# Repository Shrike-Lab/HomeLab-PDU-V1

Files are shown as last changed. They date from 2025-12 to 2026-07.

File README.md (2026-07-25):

<div align="center">
  Shrike Lab logo
  
  [Website](https://www.shrikelab.co) | [YouTube](https://www.youtube.com/@ShrikeLab)
  
</div>
<p align="center">
  <a href="https://patreon.com/shrikelab">
    
  </a>
  <a href="https://ko-fi.com/shrikelab">
    
  </a>
</p>

# **ShrikeLab PDU V1** - 5 & 10 port USB-C PDUs for 10" and 19" racks
These PSUs are power delivery solutions for micro PC clusters and homelabs that suits either 10" and 19" racks. All variants are built around a Meanwell HRP-300-24 featuring either 5 or 10 USB-C power delivery ports enclosed in sheet metal or 3D printed ABS/ASA housings. 

<div align="center">
  <a
    href="https://www.Shrikelab.co" title="Kits and PCBs available now!">Kits and PCBs available now!
  </a>  
</div>

---

<p float="center">
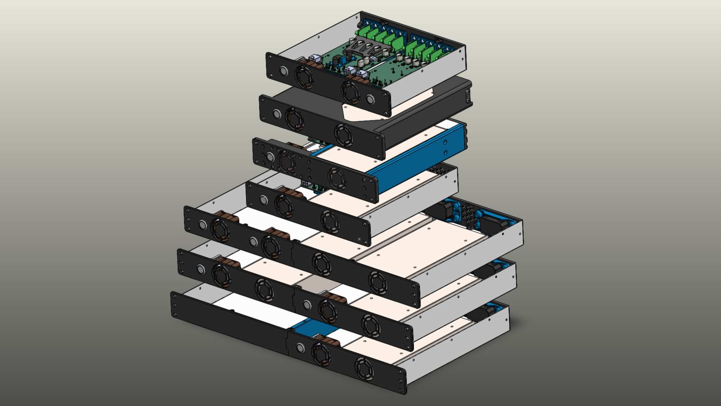
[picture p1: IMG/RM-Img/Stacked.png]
   
</p>

Mini and micro labs are a great solution for homelabbing, but the power delivery options are often bulky and hard to manage due to the need for an individual power brick per computer.
This project helps fix this by consolidating power delivery for up to 10 65W micro PCs into a single unit that fits in either a 10" or 19" 1U rack. This differs from a conventional multi-port USB PD hub by not needing to re-negotiate any power delivery voltages when a unit is turned off or unplugged, or when the power load across ports changes drastically. Also the packaging is designed specifially for rack mounting, with active cooling and simple power switching.

[**Design and build video here**](https://www.youtube.com/watch?v=8tTG0TBM7ts)

[**Follow-up and testing video here**](https://www.youtube.com/watch?v=Ig7oZpujHtc&t)

<br>

### Features:
- Both 19" and 10" variants
- Up to 10 x 65W USB-C outputs
- 1U Height
- Active cooling
- Sheet metal housing or fully 3D printable
- All variants built around a Meanwell HRP-300-24
- All 3D printed parts fit on a 220x220mm print bed

<br>

### Repo Content:
- **Assembly** - Renders and references for main and sub-assemblies, plus bill of material for each variant
  - **CAD** - CAD files for all varients, universal files and drawings of components
    - **Universal** - Files thats are used for multiple variants
    - 10in_Single
    - 10in_Dual
    - 10in_3D_Modular
    - 10in_3D_Unibody
    - 19in_Single
    - 19in_Dual
    - 19in_Dual_SBS
    - **Blanks** - STP files for customisation
    - **Universal** - STL and STP files that are used for multiple variants
  - **Drawings** - Drawings of components and wiring
    - **Electrical** - Harness pinouts and drawings of electronic components
    -  **Hardware** - Drawings of hardware along with sheet metal engineering drawings
- **IMG** - Images
- **PCB** - PCB gerber manufacturing files

<br>

### Issues:
There's a lot of ground to cover with this repo, so if you find an issue, please raise it with the GitHub issue system and it will get fixed. If you have questions about assembly or any of the variants, please make sure you have read through all the readme content before reaching out to save on time.

### ToDo:
- Export all sheet metal STEP files in 1.2mm thickness for imperial

# Variants:
All variants are built around a Meanwell HRP-300-24 and the same PCB. The housings are designed to fit in 1U of space in either a 10in and 19in server rack. 

## 10 Inch - Single:
The original 10" enclosure, a sheet metal body + lid make up the housing, with a 3D printed front and rear. 5 outputs.
<p float="center">
   
</p>
<p float="center">
   
   
</p>

[Bill of materials](https://github.com/Shrike-Lab/MiniLab-PSU/blob/main/ASSEMBLY/README.md#10-inch---single)

<br>

## 10 Inch - 3D Printed - Unibody:
10" printed unibody enclosure, made to be as easy as possible with minimal additional hardware, with the trade-off of being a little harder to print. No inserts required, all bolts thread directly into the print material. Small hatch for attaching button + fan and connecting wiring to PCB.
<p float="center">
   
</p>
<p float="center">
   
   
</p>

[Bill of materials](https://github.com/Shrike-Lab/MiniLab-PSU/blob/main/ASSEMBLY/README.md#10-inch---3d-printed---unibody)

<br>

## 10 Inch - 3D Printed - Modular:
10" printed enclosure, made to be more modular and mod-friendly but requires more M3 inserts and bolts to assebmle. The CAD folder for this variant also includes 'flipped' front and rear STLs that have the mounting tabs swapped, so that the USB-C ports and power intput will face the front of the rack instead of the rear.
<p float="center">
   
</p>
<p float="center">
   
   
</p>

[Bill of materials](https://github.com/Shrike-Lab/MiniLab-PSU/blob/main/ASSEMBLY/README.md#10-inch---3d-printed---modular)

<br>

## 10 Inch - Dual:
10" enclosure for external PSU's. 10 outputs, intended for use with alternative power sources like battery or solar, or for up-cycling external 300W PSUs.
<p float="center">
   
</p>
<p float="center">
   
   
</p>

[Bill of materials](https://github.com/Shrike-Lab/MiniLab-PSU/blob/main/ASSEMBLY/README.md#10-inch---dual)

<br>

## 19 Inch - Single:
19" inch version of 5 output variant. Additional space could be used for cable / tiny-mini-micro storage.
<p float="center">
   
</p>
<p float="center">
   
   
</p>

[Bill of materials](https://github.com/Shrike-Lab/MiniLab-PSU/blob/main/ASSEMBLY/README.md#19-inch---single)

<br>

## 19 Inch - Dual:
19" with 10 outputs from 2 x internal assemblies.
<p float="center">
   
</p>
<p float="center">
   
   
</p>

[Bill of materials](https://github.com/Shrike-Lab/MiniLab-PSU/blob/main/ASSEMBLY/README.md#19-inch---dual)

<br>

## 19 Inch - SBS:
For people that couldn't possibly deal with a power input in the middle of the housing, this version has matching components side-by-side so inputs and outputs can be coordinated easier. One harness will require extending due to the layout.
<p float="center">
   
</p>
<p float="center">
   
   
</p>

[Bill of materials](https://github.com/Shrike-Lab/MiniLab-PSU/blob/main/ASSEMBLY/README.md#19-inch---dual---sbs)

<br>

# Disclaimer:

If you build, modify, or use this project, you do so entirely at your own risk. The author provides these files without any warranty or guarantee of safety, reliability, or fitness for any particular purpose, and accepts no liability for any damage, injury, loss, or other consequences resulting from their use.

# License:
This project is licensed under the CERN Open Hardware Licence Version 2 - Strongly Reciprocal (CERN-OHL-S v2).
You may use, study, modify, and distribute this design and its documentation, provided that any derivatives are licensed under the same terms. Source design files must be made available to anyone who receives the hardware or design files.

Learn more about the license at [ohwr.org](https://ohwr.org).

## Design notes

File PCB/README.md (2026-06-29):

# PCB:
All variants use the same 2 layer 1.6mm thick PCB. This folder contains production files that can be uploaded to a PCB service for manufacturing, JLCPCB is my go-to. PCB assembly is recommended unless you have capability to do SMD soldering with either a hot air station or reflow oven.
There is currently no option for a through-hole variant because the tranistor does not come in a TH package.

**Parameters for PCB manufacturing:**
- 2 Oz copper trace weight - This is a must for current rating
- 1.6mm PCB thickness

<br>

### PCB Notes:
- You can use either an LM2596S or and MP1584EN. Just move the mounting headers to the corresponding holes.
- Connectors J19, J20, J21, J22 are optional. Either used for additional power output, or testing.
- After assembly, set fan header output voltage **before** plugging any fans in.

<br>

### Power Delivery Modules:
THe board assembly contains 5 USB-C power delivery modules that are based on an XPM52C with the following power profiles.

12V/3A, 15V/3A, 20V/3.25A

**Low Power PDO:** 5V/3A, 9V/3A, 12V/2.5A, 20V/1.5A

**High Power PDO:** 5V/3A, 9V/3A, 12V/3A

There's an interesting article [here](https://mysku.club/blog/aliexpress/101076.html) (is in Russian so will need translating) that goes over the thermal performance of the power delivery chips at 65W.

<p float="center">
   
</p>

### Buck Converter:
To power the 40mm chassis fans the main 24V rail needs to be stepped down to 12V. This can be done with either an LM2596S or MP1584EN, on the PCB there's header holes and labels for both. The LM2596S is much more popular, but the MP1584EN is newer and has less EMC. MP1584EN comes in multiple variants, **make sure to get the variable one so you're able to tune the fan voltage**.

<p float="center">
   
   
</p>

### Cooling Fan:
The cooling fan used for the PCB is a Noctua NF-A4x20 powered via 12V stepped down from the switched 24V output. This fan is 40mmx40mm and 20mm thick. The fan output on the main PCB is DC only, so the 3-Pin FLX variant are recommended, however the 4-pin PWM version will also work. When assembling the main PCB, make sure to adjust the buck converter output voltage down below 12V before plugging in any fans. The RPM of the fans is adjusted by tuning the voltage output of the buck converter.

Replacing the internal fan of the Meanwell PSU requires opening the power supply unit. This should only be attempted by qualified personnel.
Mains voltage is present inside the PSU enclosure and can cause serious injury or death. Even with the unit powered off and unplugged, capacitors inside the PSU may retain a lethal charge for an extended period. Do not touch any internal components unless you are certain the unit has been fully discharged.

If you chose to replace the PSU fan, it can be plugged into the second header on the main PCB.

The fan headers on the PCB are 3 pin 2.54mm, standard DC fan headers.

### Wiring:
There are two harnesses per set of internal electronics, one for main power and one for the button. The drawings can be found [here](https://github.com/Shrike-Lab/MiniLab-PSU/tree/main/ASSEMBLY/DRAWINGS/Electrial).

- **I would highly recommend you double check the pinout of your latching button before wiring it up, as they can differ from brand to brand.**

| Part | Harness | Quantity Per Assembly | Link |
| --- | --- | --- | --- |
| Ring spade | 24V Power | 9 | https://www.digikey.com/en/products/detail/molex/0193240008/3884473 |
| PCB Connector | 24V Power & Button | 2 | https://www.digikey.com/en/products/detail/molex/0039012060/61379?s=N4IgTCBcDaIOoFkDMB2ADGAtAOQCIgF0BfIA |
| Crimp | 24V Power & Button | 12 | https://www.digikey.com/en/products/detail/molex/0039000039/61448?s=N4IgTCBcDaIOoFkwFYAMBGAtAOQCIgF0BfIA |
| IEC Terminals | Mains Power | 7 | https://www.digikey.com/en/products/detail/molex/0190030011/279039 |

<br>

## PCB Component BOM:

| Type | Key | Value | Footprint | Quantity | Component | Commment |
| --- | --- | --- | --- | --- | --- | --- |
| Capacitor | C1,C2,C5,C6,C7,C8,C9 | 470uF | THT-CP_Radial_D10 | 6 | - | - |
| Capacitor | C3 | 1uF | 1206 | 1 | - | - |
| Capacitor | C4 | 220nF | 0603 | 1 | - | - |
| Capacitor | C10,C11,C12,C13,C14  | 1uF | 1206 | 5 | - | - |
| Capacitor | C15,C16,C17,C18,C19  | .1uF | 0603 | 5 | - | - |
| Resistor  | R1 | 4.7k | 1206 | 1 | - | - |
| Resistor  | R2 | 47k | 0603 | 1 | - | - |
| Resistor  | R3 | 100 | 0603 | 1 | - | - |
| Resistor  | R4 | 100k | 0603 | 1 | - | - |
| Diode | D1,D2,D3,D4,D5 | SMBJ26A | D_SMB | 5 | - | - |
| Diode | D6 | SMCJ26A | D_SMC | 1 | - | - |
| Diode | D7 | Zener | SOD-123 | 1 | BZT52C12 | - |
| Fuse | F1 | 15A | 2410 | 1 | 0451020.MRL | - |
| Fuse | F2,F3,F4F5,F6 | 3A | 1206 | 5 | 1206FA-4A | - |
| Connector | J1,J2 | - | Molex_5569-06A2 | 2 | Molex_5569-06A2 | Power and button |
| Connector | J13,J14,J15,J16 | - | 1x01_2.54mm | 4 | 1x01_2.54mm | Buck converter |
| Connector | J17,J18 | - | Molex_2272031 | 2 | Molex_2272031 | Fans |
| Connector | J19,J21,J22 | - | 1x02_2.54mm | 3 | 1x02_2.54mm | Debug |
| Connector | J20 | - | JST_PH-K_1x02 | 1 | JST_PH-K_1x02 | PSU sense |
| Mosfet | Q1 | - | TO-263-2L | 1 | NCEP40PT15D | - |

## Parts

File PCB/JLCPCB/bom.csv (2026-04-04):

Designator | Footprint | Quantity | Value | LCSC Part #
C1, C2, C5, C6, C7, C8, C9 | CP_Elec_10x10 | 7 | 470uF
C10, C11, C12, C13, C14, C3 | 1206 | 6 | 1uF
C15, C16, C17, C18, C19 | 0603 | 5 | .1uF
C4 | 0603 | 1 | 220nF
D1, D2, D3, D4, D5 | D_SMB | 5 | SMBJ26A
D6 | D_SMB-SMC_Universal_Handsoldering | 1 | SMCJ26A
D7 | D_SOD-123 | 1 | 12V Zener
F1 | 2410 Fuse | 1 | Fuse_0
F2 | 1206 | 1 | Fuse_1
F3 | 1206 | 1 | Fuse_2
F4 | 1206 | 1 | Fuse_3
F5 | 1206 | 1 | Fuse_4
F6 | 1206 | 1 | Fuse_5
J1 | Molex_Mini-Fit_Jr_5569-06A2_2x03_P4.20mm_Horizontal | 1 | Power_Input
J10 | PinHeader_1x01_P2.54mm_Vertical | 1 | 3_Neg
J11 | PinHeader_1x01_P2.54mm_Vertical | 1 | 4_Neg
J12 | PinHeader_1x01_P2.54mm_Vertical | 1 | 5_Neg
J17 | PinHeader_1x03_P2.54mm_Vertical | 1 | Fan_1
J18 | PinHeader_1x03_P2.54mm_Vertical | 1 | Fan_2
J2 | Molex_Mini-Fit_Jr_5569-06A2_2x03_P4.20mm_Horizontal | 1 | Button_Input
J20 | JST_PH_B2B-PH-K_1x02_P2.00mm_Vertical | 1 | Sens
J3 | PinHeader_1x01_P2.54mm_Vertical | 1 | 1_Pos
J4 | PinHeader_1x01_P2.54mm_Vertical | 1 | 2_Pos
J5 | PinHeader_1x01_P2.54mm_Vertical | 1 | 3_Pos
J6 | PinHeader_1x01_P2.54mm_Vertical | 1 | 4_Pos
J7 | PinHeader_1x01_P2.54mm_Vertical | 1 | 5_Pos
J8 | PinHeader_1x01_P2.54mm_Vertical | 1 | 1_Neg
J9 | PinHeader_1x01_P2.54mm_Vertical | 1 | 2_Neg
Q1 | TO-263-3_TabPin2 | 1 | NCEP40PT15D | IRF9540NPBF
R1 | 1206 | 1 | 4.7k
R2 | 0603 | 1 | 47k
R3 | 0603 | 1 | 100
R4 | 0603 | 1 | 100k

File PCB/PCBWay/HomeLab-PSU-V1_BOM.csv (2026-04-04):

Designator | Quantity | Value | Footprint | Package | MPN | DNP | Mount_Type | Description | Digi-Key_PN | Category | Family | DK_Datasheet_Link | DK_Detail_Page | Description_1 | Manufacturer | Status
C1, C2, C5, C6, C7, C8, C9 | 7 | 470uF | CP_Elec_10x10 |  |  |  | smt | Unpolarized capacitor
C10, C11, C12, C13, C14, C3 | 6 | 1uF | C_1206_3216Metric_Pad1.33x1.80mm_HandSolder |  |  |  | smt | Unpolarized capacitor
C15, C16, C17, C18, C19 | 5 | .1uF | C_0603_1608Metric_Pad1.08x0.95mm_HandSolder |  |  |  | smt | Unpolarized capacitor
C4 | 1 | 220nF | C_0603_1608Metric_Pad1.08x0.95mm_HandSolder |  |  |  | smt | Unpolarized capacitor
D1, D2, D3, D4, D5 | 5 | SMBJ26A | D_SMB |  |  |  | smt | 20V 2A Schottky Barrier Rectifier Diode, SMB
D6 | 1 | SMCJ26A | D_SMB-SMC_Universal_Handsoldering |  |  |  | smt | 20V 2A Schottky Barrier Rectifier Diode, SMB
D7 | 1 | 12V Zener | D_SOD-123 |  |  |  | smt | Zener diode
F1 | 1 | Fuse_0 | 2410 Fuse |  |  |  | tht | Fuse
F2 | 1 | Fuse_1 | Fuse_1206_3216Metric_Pad1.42x1.75mm_HandSolder |  |  |  | smt | Fuse
F3 | 1 | Fuse_2 | Fuse_1206_3216Metric_Pad1.42x1.75mm_HandSolder |  |  |  | smt | Fuse
F4 | 1 | Fuse_3 | Fuse_1206_3216Metric_Pad1.42x1.75mm_HandSolder |  |  |  | smt | Fuse
F5 | 1 | Fuse_4 | Fuse_1206_3216Metric_Pad1.42x1.75mm_HandSolder |  |  |  | smt | Fuse
F6 | 1 | Fuse_5 | Fuse_1206_3216Metric_Pad1.42x1.75mm_HandSolder |  |  |  | smt | Fuse
J1 | 1 | Power_Input | Molex_Mini-Fit_Jr_5569-06A2_2x03_P4.20mm_Horizontal |  |  |  | tht | Generic connector, double row, 02x03, counter clockwise pin numbering scheme (similar to DIP package numbering), script generated (kicad-library-utils/schlib/autogen/connector/)
J10 | 1 | 3_Neg | PinHeader_1x01_P2.54mm_Vertical |  |  |  | tht | Generic connector, single row, 01x01, script generated
J11 | 1 | 4_Neg | PinHeader_1x01_P2.54mm_Vertical |  |  |  | tht | Generic connector, single row, 01x01, script generated
J12 | 1 | 5_Neg | PinHeader_1x01_P2.54mm_Vertical |  |  |  | tht | Generic connector, single row, 01x01, script generated
J17 | 1 | Fan_1 | PinHeader_1x03_P2.54mm_Vertical |  |  |  | tht | Generic connector, single row, 01x03, script generated
J18 | 1 | Fan_2 | PinHeader_1x03_P2.54mm_Vertical |  |  |  | tht | Generic connector, single row, 01x03, script generated
J2 | 1 | Button_Input | Molex_Mini-Fit_Jr_5569-06A2_2x03_P4.20mm_Horizontal |  |  |  | tht | Generic connector, double row, 02x03, counter clockwise pin numbering scheme (similar to DIP package numbering), script generated (kicad-library-utils/schlib/autogen/connector/)
J20 | 1 | Sens | JST_PH_B2B-PH-K_1x02_P2.00mm_Vertical |  |  |  | tht | Generic connector, single row, 01x02, script generated
J3 | 1 | 1_Pos | PinHeader_1x01_P2.54mm_Vertical |  |  |  | tht | Generic connector, single row, 01x01, script generated
J4 | 1 | 2_Pos | PinHeader_1x01_P2.54mm_Vertical |  |  |  | tht | Generic connector, single row, 01x01, script generated
J5 | 1 | 3_Pos | PinHeader_1x01_P2.54mm_Vertical |  |  |  | tht | Generic connector, single row, 01x01, script generated
J6 | 1 | 4_Pos | PinHeader_1x01_P2.54mm_Vertical |  |  |  | tht | Generic connector, single row, 01x01, script generated
J7 | 1 | 5_Pos | PinHeader_1x01_P2.54mm_Vertical |  |  |  | tht | Generic connector, single row, 01x01, script generated
J8 | 1 | 1_Neg | PinHeader_1x01_P2.54mm_Vertical |  |  |  | tht | Generic connector, single row, 01x01, script generated
J9 | 1 | 2_Neg | PinHeader_1x01_P2.54mm_Vertical |  |  |  | tht | Generic connector, single row, 01x01, script generated
Q1 | 1 | NCEP40PT15D | TO-263-3_TabPin2 |  | IRF9540NPBF |  | smt | MOSFET P-CH 100V 23A TO-220AB | IRF9540NPBF-ND | Discrete Semiconductor Products | Transistors - FETs, MOSFETs - Single | https://www.infineon.com/dgdl/irf9540npbf.pdf?fileId=5546d462533600a401535611cfa21dc8 | /product-detail/en/infineon-technologies/IRF9540NPBF/IRF9540NPBF-ND/812088 | MOSFET P-CH 100V 23A TO-220AB | Infineon Technologies | Active
R1 | 1 | 4.7k | R_1206_3216Metric |  |  |  | smt | Resistor
R2 | 1 | 47k | R_0603_1608Metric |  |  |  | smt | Resistor
R3 | 1 | 100 | R_0603_1608Metric |  |  |  | smt | Resistor
R4 | 1 | 100k | R_0603_1608Metric |  |  |  | smt | Resistor

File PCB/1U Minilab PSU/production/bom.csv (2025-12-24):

Designator | Footprint | Quantity | Value | LCSC Part #
C1 | 0603 | 1 | 220nF
C10, C13, C19, C2, C7 | 0603 | 5 | .1uF
C11, C14, C17, C3, C4, C8 | CP_Radial_D10.0mm_P5.00mm | 6 | 470uF
C12, C15, C18, C5, C6, C9 | 1206 | 6 | 1uF
C16 | CP_Radial_D10.0mm_P5.00mm | 1 | 1000uF
D1, D2, D3, D4, D7 | D_SMB | 5 | SMBJ24A
D5 | D_SOD-123 | 1 | D_Zener
D6 | D_SMB-SMC_Universal_Handsoldering | 1 | SMCJ24A
F1 | 1206 | 1 | Fuse_1
F2 | 1206 | 1 | Fuse_2
F3 | 1206 | 1 | Fuse_3
F4 | 1206 | 1 | Fuse_4
F5 | 1206 | 1 | Fuse_0
F6 | 1206 | 1 | Fuse_5
J1 | Molex_Micro-Fit_3.0_43045-0600_2x03_P3.00mm_Horizontal | 1 | Power_Input
J10 | PinHeader_1x01_P2.54mm_Vertical | 1 | 4_Neg
J11, J12 | PinHeader_1x03_P2.54mm_Vertical | 2 | Conn_01x03_Pin
J13 | PinHeader_1x02_P2.54mm_Vertical | 1 | Conn_01x02_Pin
J14 | PinHeader_1x01_P2.54mm_Vertical | 1 | Fan-IN
J15 | PinHeader_1x01_P2.54mm_Vertical | 1 | Fan+IN
J16 | PinHeader_1x01_P2.54mm_Vertical | 1 | Fan+Out
J17 | PinHeader_1x01_P2.54mm_Vertical | 1 | Fan-Out
J18 | PinHeader_1x01_P2.54mm_Vertical | 1 | 5_Pos
J19 | PinHeader_1x01_P2.54mm_Vertical | 1 | 5_Neg
J2 | Molex_Micro-Fit_3.0_43045-0600_2x03_P3.00mm_Horizontal | 1 | Button_Input
J20 | PinHeader_1x02_P2.54mm_Vertical | 1 | Sens
J21, J22 | PinHeader_1x02_P2.54mm_Vertical | 2 | 24V
J3 | PinHeader_1x01_P2.54mm_Vertical | 1 | 1_Pos
J4 | PinHeader_1x01_P2.54mm_Vertical | 1 | 1_Neg
J5 | PinHeader_1x01_P2.54mm_Vertical | 1 | 2_Pos
J6 | PinHeader_1x01_P2.54mm_Vertical | 1 | 2_Neg
J7 | PinHeader_1x01_P2.54mm_Vertical | 1 | 3_Pos
J8 | PinHeader_1x01_P2.54mm_Vertical | 1 | 3_Neg
J9 | PinHeader_1x01_P2.54mm_Vertical | 1 | 4_Pos
Q4 | TO-252-3_TabPin2 | 1 | DMP4010SK3-13 | IRF9540NPBF
R3 | 0603 | 1 | 100
R4 | 0603 | 1 | 47k
R5 | 1206 | 1 | 4.7k
R6 | 0603 | 1 | 100k

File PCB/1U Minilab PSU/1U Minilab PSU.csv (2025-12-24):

Reference | Qty | Value | DNP | Exclude from BOM | Exclude from Board | Footprint | Datasheet | Part
C1 | 1 | 220nF |  |  |  | Capacitor_SMD:C_0603_1608Metric_Pad1.08x0.95mm_HandSolder | ~
C2,C7,C10,C13 | 4 | .1uF |  |  |  | Capacitor_SMD:C_0603_1608Metric_Pad1.08x0.95mm_HandSolder | ~
C3,C4,C8,C11,C14 | 5 | 470uF |  |  |  | Capacitor_THT:CP_Radial_D10.0mm_P5.00mm | ~ | https://www.digikey.co.nz/en/products/detail/kemet/A759MS477M1EAAE020/13676499
C5,C6,C9,C12,C15 | 5 | 1uF |  |  |  | Capacitor_SMD:C_1206_3216Metric_Pad1.33x1.80mm_HandSolder | ~
C16 | 1 | 1000uF |  |  |  | Capacitor_THT:CP_Radial_D10.0mm_P5.00mm | ~
D1,D2,D3,D4 | 4 | SMBJ24A |  |  |  | Diode_SMD:D_SMA-SMB_Universal_Handsoldering
D5 | 1 | D_Zener |  |  |  | Diode_SMD:D_SOD-123 | ~
D6 | 1 | SMCJ24A |  |  |  | Diode_SMD:D_SMB-SMC_Universal_Handsoldering
F1 | 1 | Fuse_1 |  |  |  | Fuse:Fuse_1206_3216Metric_Pad1.42x1.75mm_HandSolder | ~ | https://www.digikey.co.nz/en/products/detail/bourns-inc/SF-1206F350M-2/14320025
F2 | 1 | Fuse_2 |  |  |  | Fuse:Fuse_1206_3216Metric_Pad1.42x1.75mm_HandSolder | ~ | https://www.digikey.co.nz/en/products/detail/bourns-inc/SF-1206F350M-2/14320025
F3 | 1 | Fuse_3 |  |  |  | Fuse:Fuse_1206_3216Metric_Pad1.42x1.75mm_HandSolder | ~ | https://www.digikey.co.nz/en/products/detail/bourns-inc/SF-1206F350M-2/14320025
F4 | 1 | Fuse_4 |  |  |  | Fuse:Fuse_1206_3216Metric_Pad1.42x1.75mm_HandSolder | ~ | https://www.digikey.co.nz/en/products/detail/bourns-inc/SF-1206F350M-2/14320025
F5 | 1 | Fuse_0 |  |  |  | Fuse:Fuse_1206_3216Metric_Pad1.42x1.75mm_HandSolder | ~ | https://www.digikey.co.nz/en/products/detail/schurter-inc/3413-0329-22/2644176
Q4 | 1 | DMP4010SK3-13 |  |  |  | Package_TO_SOT_SMD:TO-252-3_TabPin2
R2 | 1 | 0 | DNP |  |  | Resistor_SMD:R_1206_3216Metric | ~
R3 | 1 | 100 |  |  |  | Resistor_SMD:R_0603_1608Metric | ~
R4 | 1 | 47k |  |  |  | Resistor_SMD:R_0603_1608Metric | ~
R5 | 1 | 4.7k |  |  |  | Resistor_SMD:R_1206_3216Metric | ~
R6 | 1 | 100k |  |  |  | Resistor_SMD:R_0603_1608Metric | ~

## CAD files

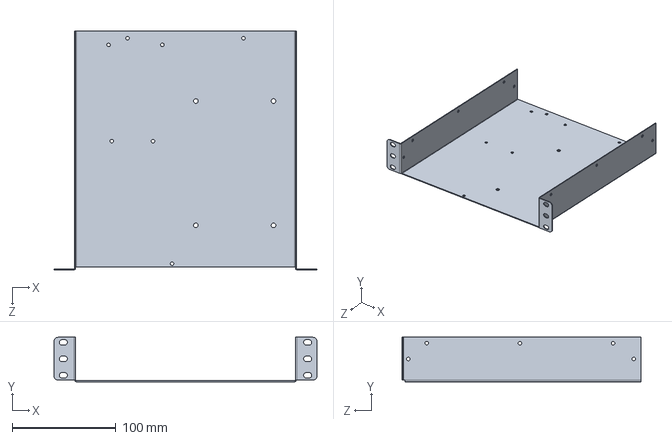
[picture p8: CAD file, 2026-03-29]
ASSEMBLY/CAD/10in_Single/Metal_Tray.STEP
254.0 x 43.0 x 230.5 mm

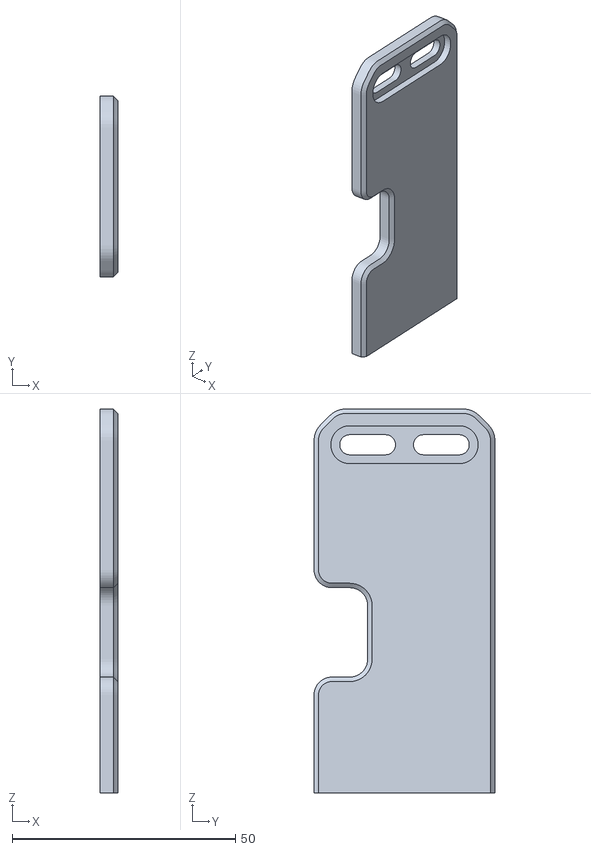
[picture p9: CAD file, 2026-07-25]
ASSEMBLY/CAD/19in_Dual_SBS/19in_Dual_SBS-Divider.STL
4.00 x 40.5 x 86.0

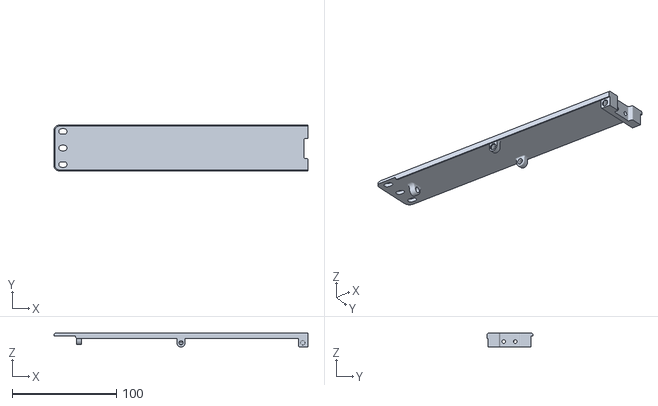
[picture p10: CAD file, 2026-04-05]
ASSEMBLY/CAD/19in_Single/19in_Single-Rear_2.stl
244.1 x 44.0 x 13.4

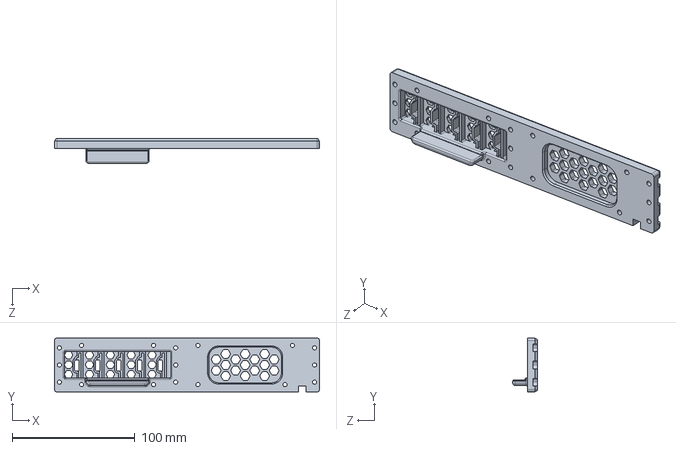
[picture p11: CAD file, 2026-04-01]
ASSEMBLY/CAD/Blanks/10in_Mod-Back-BLANK.STEP
216.0 x 44.0 x 20.0 mm

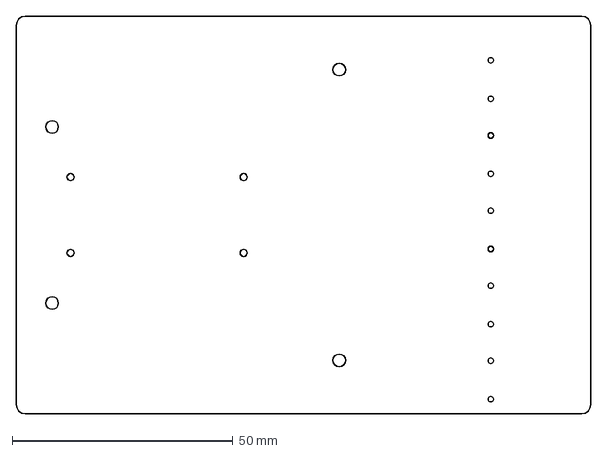
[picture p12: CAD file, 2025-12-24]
PCB/1U Minilab PSU/Breakout PCB Outline.DXF
130.0 x 90.0 mm

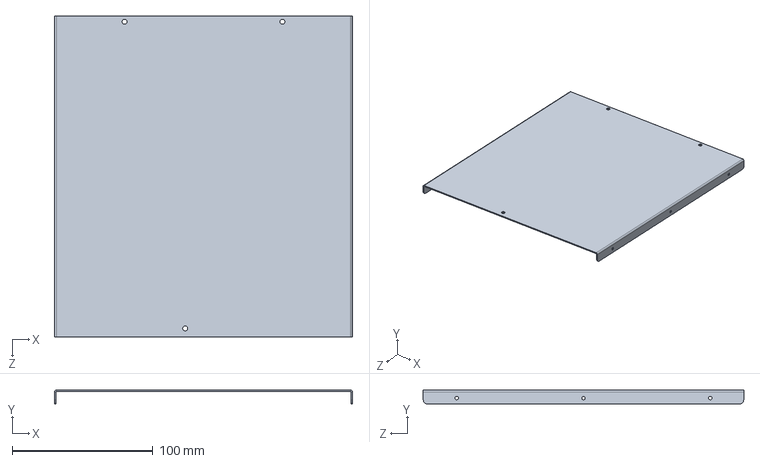
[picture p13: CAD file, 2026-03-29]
ASSEMBLY/CAD/10in_Single/Metal_Lid.STEP
211.5 x 10.0 x 227.5 mm

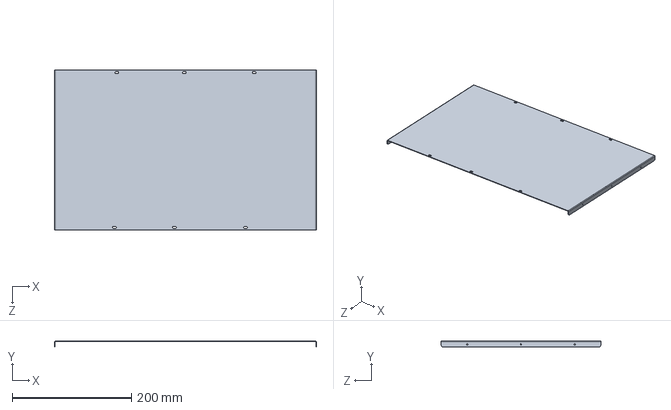
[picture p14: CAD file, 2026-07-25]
ASSEMBLY/CAD/19in_Dual_SBS/19in_Dual_SBS-Lid.stp
438.7 x 10.0 x 267.1 mm

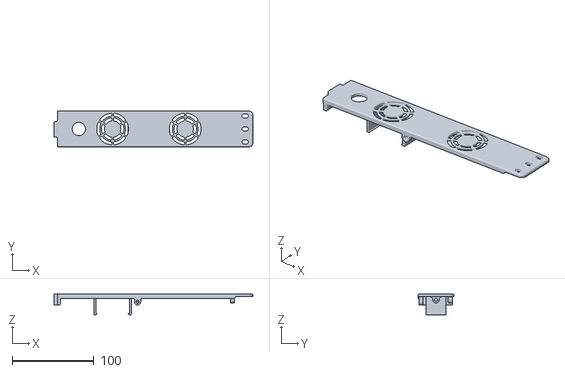
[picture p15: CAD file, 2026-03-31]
ASSEMBLY/CAD/19in_Single/19in_Single-Front_1.stl
244.0 x 44.0 x 25.5

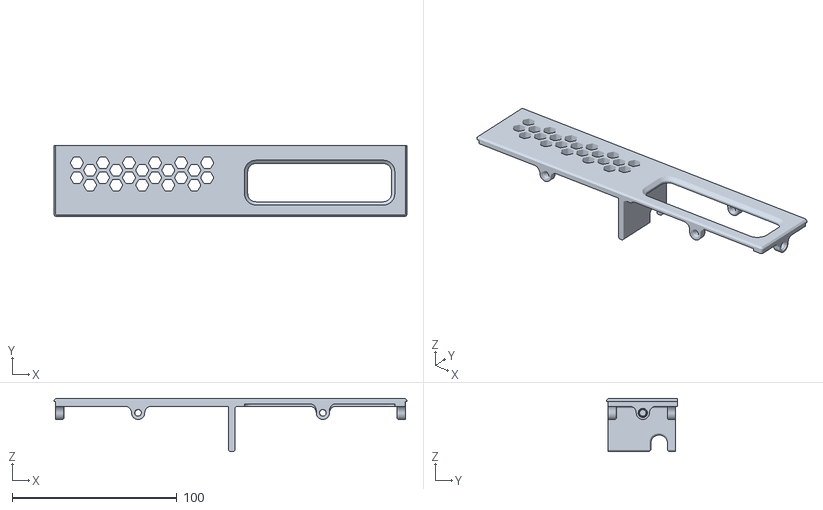
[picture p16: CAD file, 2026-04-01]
ASSEMBLY/CAD/Blanks/10in_Single-Back-BLANK.STL
214.0 x 43.0 x 32.3

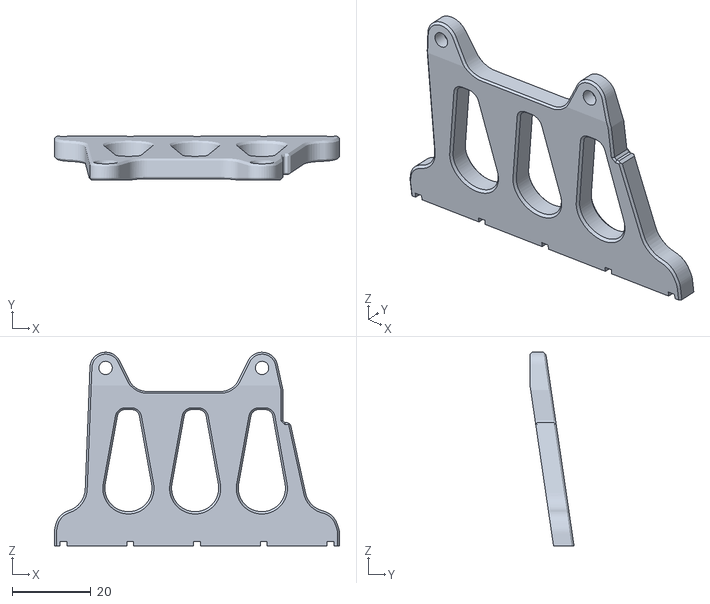
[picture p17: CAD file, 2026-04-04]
ASSEMBLY/CAD/Universal/Reinforcement_Bracket.stl
72.6 x 11.2 x 49.3

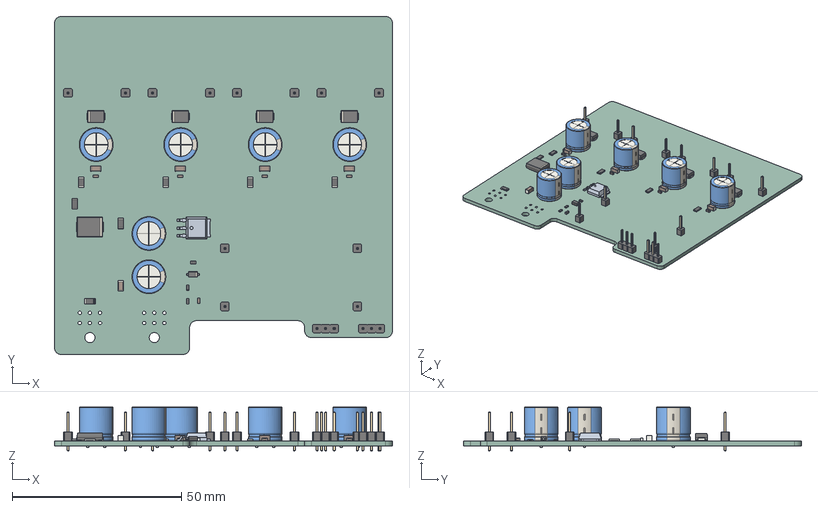
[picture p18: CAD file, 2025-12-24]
PCB/1U Minilab PSU/1U Minilab PSU.step
100.0 x 100.0 x 13.0 mm
C_1206_3216Metric x 5
PinHeader_1x01_P2.54mm_Vertical x 12
CP_Radial_D10.0mm_P5.00mm x 6
D_SMB x 4
D_SMC
1U Minilab PSU 1.11.1
PinHeader_1x03_P2.54mm_Vertical x 2
Fuse_1206_3216Metric x 5
C_0603_1608Metric x 5
R_0603_1608Metric x 3
R_1206_3216Metric x 2
D_SOD-123
1U Minilab PSU_PCB

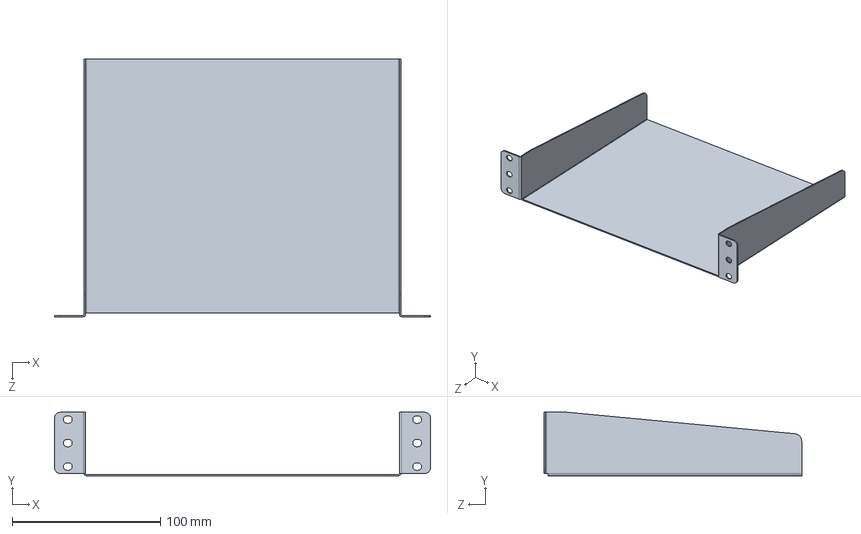
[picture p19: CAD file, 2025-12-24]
PCB/1U Minilab PSU/CAD/Optiplex_Tray.SLDPRT
254.0 x 43.0 x 174.0 mm

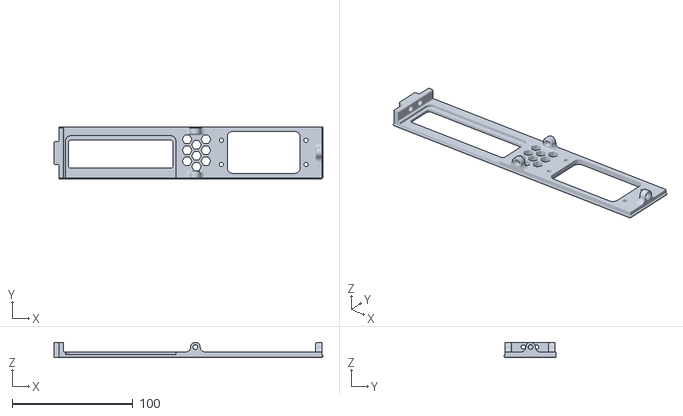
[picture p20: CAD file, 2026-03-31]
ASSEMBLY/CAD/19in_Single/19in_Single-Rear_1.stl
222.4 x 43.0 x 12.8

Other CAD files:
ASSEMBLY/CAD/19in_Dual/19in_Dual-Front_2.stl
ASSEMBLY/CAD/Universal/19in_Single-Rear_2-BLANK.STEP
PCB/1U Minilab PSU/CAD/Metal_Tray.SLDPRT
ASSEMBLY/CAD/19in_Dual/19in_Dual-Rear_2.stl
ASSEMBLY/CAD/19in_Dual/19in_Dual-Rear_1.stl
ASSEMBLY/CAD/19in_Dual/19in_Dual-Front_1.stl
ASSEMBLY/CAD/19in_Single/19in_Single-Front_2.3mf
ASSEMBLY/CAD/19in_Single/19in_Single-Front_2.stl
ASSEMBLY/CAD/Blanks/10in_Uni-Tray-BLANK.stl.STEP
ASSEMBLY/CAD/Universal/IEC_Bracket.stl
ASSEMBLY/CAD/Universal/PCB_Tray.stl
PCB/1U Minilab PSU/CAD/Metal_Lid.DXF
PCB/1U Minilab PSU/CAD/Metal_Lid.SLDPRT
PCB/1U Minilab PSU/CAD/Metal_Tray.DXF
PCB/1U Minilab PSU/CAD/Optiplex_Tray.DXF

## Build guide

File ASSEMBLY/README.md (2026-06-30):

# Assembly:
This section contains the bill of materials for each variant, as well as renders and exploded views of the sub-assemblies.

- All trays mount to the racks with M5 hardware
- For 3D printing all files have been exported as an STL
- Blank parts have been exported as an STP to help editing
- Metal parts are exported as an STP
- As the metal housing lids require tapping, there is an engineering drawing in the [drawings folder](https://github.com/Shrike-Lab/MiniLab-PSU/tree/main/ASSEMBLY/DRAWINGS/Hardware)
- Highly recommended to order extra insert and bolt hardware

**All variants contain the following components:**
| Component |Link/Location | Source |
| --- |--- | --- |
| PDU PCB Ver 1.0 | [Drawing](https://github.com/Shrike-Lab/HomeLab-PDU-V1/blob/main/PCB/Minilab_PDU_V1.zip) | Shrikelab kit or buy PCB manufacturing service|
| 16mm Button | [Drawing](https://github.com/Shrike-Lab/HomeLab-PDU-V1/blob/main/ASSEMBLY/DRAWINGS/Electrial/Harness-Button.pdf)  | Shrikelab kit or buy online |
| Button harness | [Drawing](https://github.com/Shrike-Lab/HomeLab-PDU-V1/blob/main/ASSEMBLY/DRAWINGS/Electrial/Harness-Button.pdf)| Shrikelab kit or comes with button |
| Power harness | [Drawing](https://github.com/Shrike-Lab/HomeLab-PDU-V1/blob/main/ASSEMBLY/DRAWINGS/Electrial/Harness-Power.pdf) | Shrikelab kit or DIY |
| 40mm cooling fan | - | - |

### Drawings of components can be found here:
**Hardware:**
| Component |Link/Location | Source |
| --- |--- | --- |
| M3 Low Profile Bolt | [Drawing](https://github.com/Shrike-Lab/HomeLab-PDU-V1/blob/main/ASSEMBLY/DRAWINGS/Hardware/Bolt-LowProfile.png) | - | 
| M3 Cap Head Bolt | [Drawing](https://github.com/Shrike-Lab/HomeLab-PDU-V1/blob/main/ASSEMBLY/DRAWINGS/Hardware/Bolt-CapHead.png) | - |
| M4 Low Profile Bolt | [Drawing](https://github.com/Shrike-Lab/HomeLab-PDU-V1/blob/main/ASSEMBLY/DRAWINGS/Hardware/Bolt-LowProfile.png) | - |
| M4 Cap Head Bolt | [Drawing](https://github.com/Shrike-Lab/HomeLab-PDU-V1/blob/main/ASSEMBLY/DRAWINGS/Hardware/Bolt-CapHead.png) | - | 
| M3 Insert | [Drawing](https://github.com/Shrike-Lab/HomeLab-PDU-V1/blob/main/ASSEMBLY/DRAWINGS/Hardware/M3-Insert.pdf) | - |

**Electrical:**
| Component |Link/Location | Source |
| --- |--- | --- |
| MP1584EN | [Drawing](https://github.com/Shrike-Lab/HomeLab-PDU-V1/blob/main/ASSEMBLY/DRAWINGS/Electrial/Buck_Board.png) | Online (Search term: MP1584EN Buck Converter)|
| Heatsink | [Drawing](https://github.com/Shrike-Lab/HomeLab-PDU-V1/blob/main/ASSEMBLY/DRAWINGS/Electrial/Heatsink.png) | Online (Search term: 10x10x10mm Aluminium headsink) |
| PD Board | [Drawing](https://github.com/Shrike-Lab/HomeLab-PDU-V1/blob/main/ASSEMBLY/DRAWINGS/Electrial/PD_Board.png) | Online (Search term: DC to 65w fast charging USB-C board) |

<br>

## 3D Print Settings:
It's **highly** recommended to use a high-temperature filament for any of the 3D printed parts, to avoid thermal deformation and material creep over time.
Housing components should be printed with at least 5 walls and 50% infill.

<br>

## Sub-Assemblies:
There are two assemblies that are shared between the variants using a sheet metal housing.

### PCB Tray:
This PCB tray makes soldering the daughter boards easier, and allows the board to be installed and removed from the chassis easier.
<p float="center">
   
  
  
</p>

| Component | Quantity | Link/Location |
| --- | --- | --- |
| PDU PCB Ver 1.0 | 1 | [Gerber](https://github.com/Shrike-Lab/HomeLab-PDU-V1/tree/main/PCB) | 
| PCB Tray | 1 | [STL](https://github.com/Shrike-Lab/MiniLab-PSU/blob/main/ASSEMBLY/CAD/Universal/PCB_Tray.stl) | 
| USB-C 65W PD Board | 5 | [Image](https://github.com/Shrike-Lab/MiniLab-PSU/blob/main/ASSEMBLY/DRAWINGS/Electrial/Heatsink.png) | 
| Heatsink | 5 | [Drawing](https://github.com/Shrike-Lab/MiniLab-PSU/blob/main/ASSEMBLY/DRAWINGS/Electrial/Heatsink.png) | 
| PCB Reinforement | 1 | [STL](https://github.com/Shrike-Lab/MiniLab-PSU/blob/main/ASSEMBLY/CAD/Universal/Reinforcement_Bracket.stl) | 
| Buck Converter | 1 | [Image](https://github.com/Shrike-Lab/MiniLab-PSU/blob/main/ASSEMBLY/DRAWINGS/Electrial/Buck_Board.png) | 

<br>

### IEC Plug:
Due to the extra depth allowed on full racks, all 19" variants use the IEC plug sub-assembly to allow for a detachable cable.
<p float="center">
   
</p>

| Component | Quantity | Link/Location |
| --- | --- | --- |
| IEC Socket | 1 | [Digikey part link](https://www.digikey.com/en/products/detail/adam-tech/IEC-GS-1-100/9831135) |
| IEC Bracket | 1 | [STL](https://github.com/Shrike-Lab/MiniLab-PSU/blob/main/ASSEMBLY/CAD/Universal/IEC_Bracket.stl) |
| IEC Spade Terminals | 7 | [Digikey part link](https://www.digikey.com/en/products/detail/molex/0190030011/279039) |
| IEC Fuse | 1 | [Digikey part link](https://www.digikey.com/en/products/detail/littelfuse-inc/0232008-MXP/778029) |

<br>

### PCB Assembly Bracket:
If additional assitance is required during assembly, this bracket (Yellow) can be printed to hold the boards in place. It's then removed and replaced with the reinforcment bracket when the assembly is installed into a chassis.
<p float="center">
   
</p>

<br>

# Variant BOMs:

## 10 Inch - Single:
<p float="center">
   
</p>

#### **Sub-Assemblies:**
| Assembly | Quantity |
| --- | --- |
| [PCB Tray](README.md#pcb-tray) | 1 |

#### **Housing:**
| Item  | File Name | Material | Quantity |
| ----- | --- | --- | --- |
| Tray  | 10in_Single-Tray.stp  | Sheel Metal | 1 |
| Lid | 10in_Single-Lid.stp | Sheel Metal | 1 |
| Front | 10in_Single-Front.stl | 3D Print (ABS/ASA) | 1 |
| Back  | 10in_Single-Back.stl  | 3D Print (ABS/ASA) | 1 |
[Housing files are located here](https://github.com/Shrike-Lab/MiniLab-PSU/tree/main/ASSEMBLY/CAD/10in_Single)

#### **Hardware**
| Item | Length | Quantity |
| --- | --- | --- |
| M3 Low Profile Bolt | 5mm | 24 |
| M3 Low Profile Bolt | 8mm | 2 |
| M3 Plastic Washer | - | 4 |
| M4 Low Profile Bolt | 5mm | 4 |
| M3 Insert | - | 20 |

<br>

## 10 Inch - 3D Printed - Unibody:
<p float="center">
   
</p>

#### **Sub-Assemblies:**
This variant contains no sub-assemblies still requires the [PCB reinforcement bracket](https://github.com/Shrike-Lab/MiniLab-PSU/tree/main/ASSEMBLY/CAD/Universal/Reinforcement_Bracket.stl)

#### **Housing:**
| Item | File Name | Material | Quantity |
| --- | --- | --- | --- |
| Body | 10in_Uni-Body.stl  | 3D Print (ABS/ASA) | 1 |
| Tray | 10in_Uni-Tray.stl  | 3D Print (ABS/ASA) | 1 |
| Side Panel | 10in_Uni-SidePanel | 3D Print (ABS/ASA) | 1 |
[Housing files are located here](https://github.com/Shrike-Lab/MiniLab-PSU/tree/main/ASSEMBLY/CAD/10in_3D_Unibody)

#### **Hardware**
| Item | Length | Quantity |
| --- | --- | --- |
| M3 Low Profile Bolt | 5mm | 6 |
| M3 Low Profile Bolt | 8mm | 2 |
| M3 Plastic Washer | - | 4 |
<br>

## 10 Inch - 3D Printed - Modular:
<p float="center">
   
</p>

#### **Sub-Assemblies:**
This variant contains no sub-assemblies still requires the [PCB reinforcement bracket](https://github.com/Shrike-Lab/MiniLab-PSU/tree/main/ASSEMBLY/CAD/Universal/Reinforcement_Bracket.stl)

#### **Housing:**
| Item | File Name | Material | Quantity |
| --- | --- | --- | --- |
| Front | 10in_Mod-Front.stl | 3D Print (ABS/ASA) | 1 | 
| Rear | 10in_Mod-Rear.stl | 3D Print (ABS/ASA) | 1 | 
| Left | 10in_Mod-Left.stl | 3D Print (ABS/ASA) | 1 | 
| Right | 10in_Mod-Right.stl | 3D Print (ABS/ASA) | 1 | 
| Middle | 10in_Mod-Middle.stl | 3D Print (ABS/ASA) | 1 | 
| Top_1 | 10in_Mod-Top_1.stl | 3D Print (ABS/ASA) | 1 | 
| Top_2 | 10in_Mod-Top_2.stl | 3D Print (ABS/ASA) | 1 | 
| Bottom_1 | 10in_Mod-Bottom_1.stl | 3D Print (ABS/ASA) | 1 | 
| Bottom_2 | 10in_Mod-Bottom_2.stl | 3D Print (ABS/ASA) | 1 | 
[Housing files are located here](https://github.com/Shrike-Lab/MiniLab-PSU/tree/main/ASSEMBLY/CAD/10in_3D_Modular)

#### **Hardware**
| Item | Length | Quantity |
| --- | --- | --- |
| M3 Cap Head Bolt | 8mm | 28 |
| M3 Cap Head Bolt | 16mm | 4 | 
| M3 Insert | - | 30 | 
| M4 Cap Head Bolt | 5mm | 7 |  
| M4 Low Profile Bolt | 3mm | 1 | 
| M3 Low Profile Bolt | 5mm | 2 |
| Plastic Washer | - | 2 |

<br>

## 10 Inch - Dual:
<p float="center">
   
</p>

#### **Sub-Assemblies:**
| Assembly | Quantity |
| --- | --- |
| [PCB Tray](README.md#pcb-tray) | 2 |

#### **Housing:**
| Item  | File Name | Material | Quantity |
| ----- | --- | --- | --- |
| Tray  | 10in_Dual-Tray.stp  | Sheel Metal | 1 |
| Lid | 10in_Dual-Lid.stp | Sheel Metal | 1 |
| Front | 10in_Dual-Front.stl | 3D Print (ABS/ASA) | 1 |
| Back  | 10in_Dual-Back.stl  | 3D Print (ABS/ASA) | 1 |
[Housing files are located here](https://github.com/Shrike-Lab/MiniLab-PSU/tree/main/ASSEMBLY/CAD/10in_Dual)

#### **Hardware**
| Item | Length | Quantity |
| --- | --- | --- |
| M3 Low Profile Bolt | 5mm | 32 |
| M3 Low Profile Bolt | 8mm | 4 |
| M3 Plastic Washer | - | 8 |
| M3 Insert | - | 30 |

<br>

## 19 Inch - Single:
<p float="center">
   
</p>

#### **Sub-Assemblies:**
| Assembly | Quantity |
| --- | --- |
| [PCB Tray](README.md#pcb-tray) | 1 |
| [IEC Plug](README.md#iec-plug) | 1 |

#### **Housing:**
| Item | File Name | Material | Quantity |
| --- | --- | --- | --- |
| Tray | 19in_Single-Tray.stp | Sheel Metal | 1 |
| Lid | 19in_Single-Lid.stp | Sheel Metal | 1 |
| Front-1 | 19in_Single-Front_1.stl | 3D Print (ABS/ASA) | 1 |
| Front-2 | 19in_Single-Front_2.stl | 3D Print (ABS/ASA) | 1 |
| Back-1  | 19in_Single-Back_1.stl  | 3D Print (ABS/ASA) | 1 |
| Back-2  | 19in_Single-Back_2.stl  | 3D Print (ABS/ASA) | 1 |
| Interal | 19in_Single-Internal.stl | 3D Print (ABS/ASA) | 1 |
| Divider | 19in_Single-Divider.stl | 3D Print (ABS/ASA) | 1 |

[Housing files are located here](https://github.com/Shrike-Lab/MiniLab-PSU/tree/main/ASSEMBLY/CAD/19in_Single)

#### **Hardware**
| Item | Length | Quantity |
| --- | --- | --- |
| M3 Low Profile Bolt | 5mm | 36 |
| M3 Plastic Washer | - | 4 |
| M3 Insert | - | 40 |
| M4 Low Profile Bolt | 5mm | 4 |
| M3 Cap Head | 8mm | 10 |

<br>

## 19 Inch - Dual:
<p float="center">
   
</p>

#### **Sub-Assemblies:**
| Assembly | Quantity |
| --- | --- |
| [PCB Tray](README.md#pcb-tray) | 2 |
| [IEC Plug](README.md#iec-plug) | 2 |

#### **Housing:**
| Item | File Name | Material | Quantity |
| --- | --- | --- | --- |
| Tray | 19in_Dual-Tray.stp | Sheel Metal | 1 |
| Lid | 19in_Dual-Lid.stp | Sheel Metal | 1 |
| Front-1 | 19in_Dual-Front_1.stl | 3D Print (ABS/ASA) | 1 |
| Front-2 | 19in_Dual-Front_2.stl | 3D Print (ABS/ASA) | 1 |
| Back-1  | 19in_Dual-Back_1.stl  | 3D Print (ABS/ASA) | 1 |
| Back-2  | 19in_Dual-Back_2.stl  | 3D Print (ABS/ASA) | 1 |
| Divider | 19in_Dual-Divider.stl | 3D Print (ABS/ASA) | 3 |
[Housing files are located here](https://github.com/Shrike-Lab/MiniLab-PSU/tree/main/ASSEMBLY/CAD/19in_Dual)

#### **Hardware**
| Item | Length | Quantity |
| --- | --- | --- |
| M3 Low Profile Bolt | 5mm | 42 |
| M3 Plastic Washer | - | 8 |
| M3 Insert | - | 48 |  
| M4 Low Profile Bolt | 5mm | 14 | 
| M3 Cap Head | 8mm | 16 | 

<br>

## 19 Inch - Dual - SBS:
<p float="center">
   
</p>

#### **Sub-Assemblies:**
| Assembly | Quantity |
| --- | --- |
| [PCB Tray](README.md#pcb-tray) | 2 |
| [IEC Plug](README.md#iec-plug) | 2 |

#### **Housing:**
| Item | File Name | Material | Quantity |
| --- | --- | --- | --- |
| Tray | 19in_Dual_SBS-Tray.stp | Sheel Metal | 1 |
| Lid | 19in_Dual_SBS-Lid.stp | Sheel Metal | 1 |
| Front-1 | 19in_Dual_SBS-Front_1.stl  | 3D Print (ABS/ASA) | 1 |
| Front-2 | 19in_Dual_SBS-Front_2.stl | 3D Print (ABS/ASA) | 1 |
| Back-1  | 19in_Dual_SBS-Back_1.stl  | 3D Print (ABS/ASA) | 1 |
| Back-2  | 19in_Dual_SBS-Back_2.stl  | 3D Print (ABS/ASA) | 1 |
| Divider | 19in_Dual_SBS-Divider.stl | 3D Print (ABS/ASA) | 2 |
[Housing files are located here](https://github.com/Shrike-Lab/MiniLab-PSU/tree/main/ASSEMBLY/CAD/19in_Dual_SBS)

#### **Hardware**
| Item | Length | Quantity |
| --- | --- | --- |
| M3 Low Profile Bolt | 5mm | 42 |
| M3 Plastic Washer | - | 8 | 
| M3 Insert | - | 48 | 
| M4 Low Profile Bolt | 5mm | 12 |
| M3 Cap Head | 8mm | 16 |

<br>

## Main PCB Assembly:

The small blue piece is a guide for cutting, bending and crimping the jumper wires from the PD modules to the main board.
<p float="center">
   
</p>
<br>

Along the longest edge, line up the jumper wire and cut to length.
<p float="center">
   
</p>
<br>

Jumper wire cut to length.
<p float="center">
   
</p>
<br>

Align the jumper with the bend line on the opposite side from the first step.
<p float="center">
   
</p>
<br>

While holding the jumper in place, bend around the corner.
<p float="center">
   
</p>
<br>

On the same edge used to cut the jumper to length, there is small notch which is used to show how far back to strip the wire.
<p float="center">
   
</p>
<br>

Strip both ends according to this mark and the jumper wire is complete.
<p float="center">
   
</p>
<br>

To prep the PD module, first attach the smaller (7mmx7mm) heatsink to the top of XMP PD chip, aligning the heatsinks horizontally.
<p float="center">
   
</p>
<br>

Then attach the larger (10mmx10mm) to the inductor, also aligning horizontally.
<p float="center">
   
</p>
<br>

To solder the jumpers on, it's highly recommended to hold the PD board in place with helping hands or a clamp.
<p float="center">
   
</p>
<br>

Take a 90 degree pin header and cut it from the stack, then solder in place on the positive terminal as shown.
<p float="center">
   
</p>
<br>

Flip around and solder the jumper wire onto the negative terminal of the PD module.
<p float="center">
   
</p>
<br>

Insert the module onto the main board, hold in place with either the PCB tray or dedicated bracket, then solder.
<p float="center">
   
</p>
<br>

Cut 4 straight jumpers and solder the buck converter in its dedicated spot. Making sure to line up the input and output pins correctly.
<p float="center">
   
</p>
<br>

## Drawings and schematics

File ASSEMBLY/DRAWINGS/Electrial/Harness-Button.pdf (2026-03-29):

E E

F F

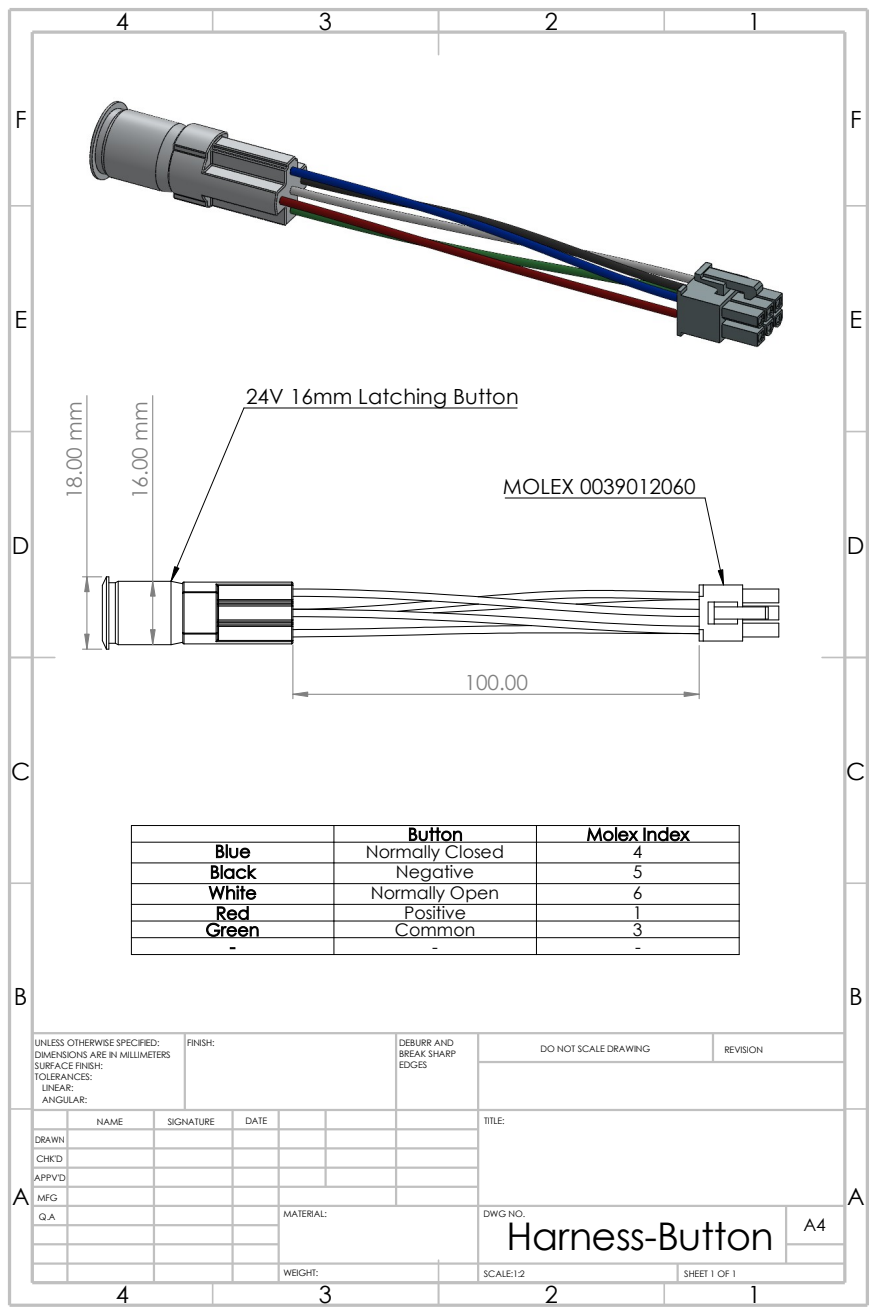
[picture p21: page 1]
MATERIAL:; REVISION; DWG NO.; SCALE:1:2; SHEET 1 OF 1; WEIGHT:; EDGES; FINISH:; MFG; DEBURR AND BREAK SHARP; Harness-Button; MOLEX 0039012060 18.00 mm; 24V 16mm Latching Button

Button | Molex Index

Blue | Normally Closed | 4
Black | Negative | 5
White | Normally Open | 6
Red | Positive | 1
Green | Common | 3

UNLESS OTHERWISE SPECIFIED:
DIMENSIONS ARE IN MILLIMETERS
SURFACE FINISH:
TOLERANCES:
LINEAR:
ANGULAR:

DO NOT SCALE DRAWING

NAME | SIGNATURE | DATE | TITLE:

DRAWN
CHK'D
APPV'D

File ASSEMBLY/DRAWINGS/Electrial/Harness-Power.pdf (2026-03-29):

E E

F F

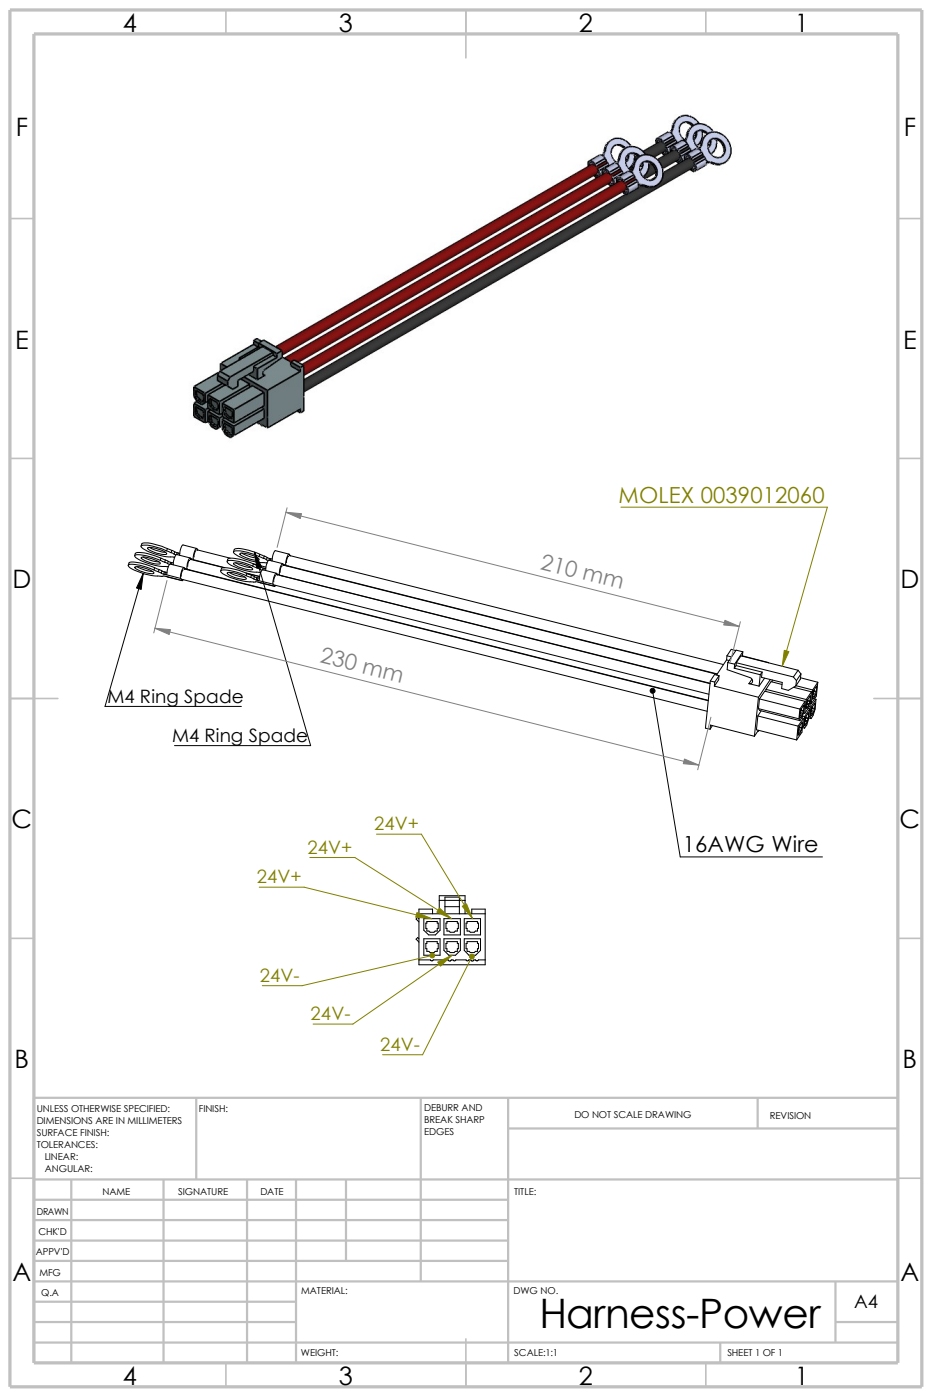
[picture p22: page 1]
DWG NO.; SCALE:1:1; SHEET 1 OF 1; WEIGHT:; DO NOT SCALE DRAWING; REVISION; MATERIAL:; MFG; FINISH:; EDGES; DEBURR AND BREAK SHARP; Harness-Power; MOLEX 0039012060; M4 Ring Spade; 16AWG Wire

UNLESS OTHERWISE SPECIFIED:
DIMENSIONS ARE IN MILLIMETERS
SURFACE FINISH:
TOLERANCES:
LINEAR:
ANGULAR:

NAME | SIGNATURE | DATE | TITLE:

DRAWN
CHK'D
APPV'D

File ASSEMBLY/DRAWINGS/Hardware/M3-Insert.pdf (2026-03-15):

E E

F F

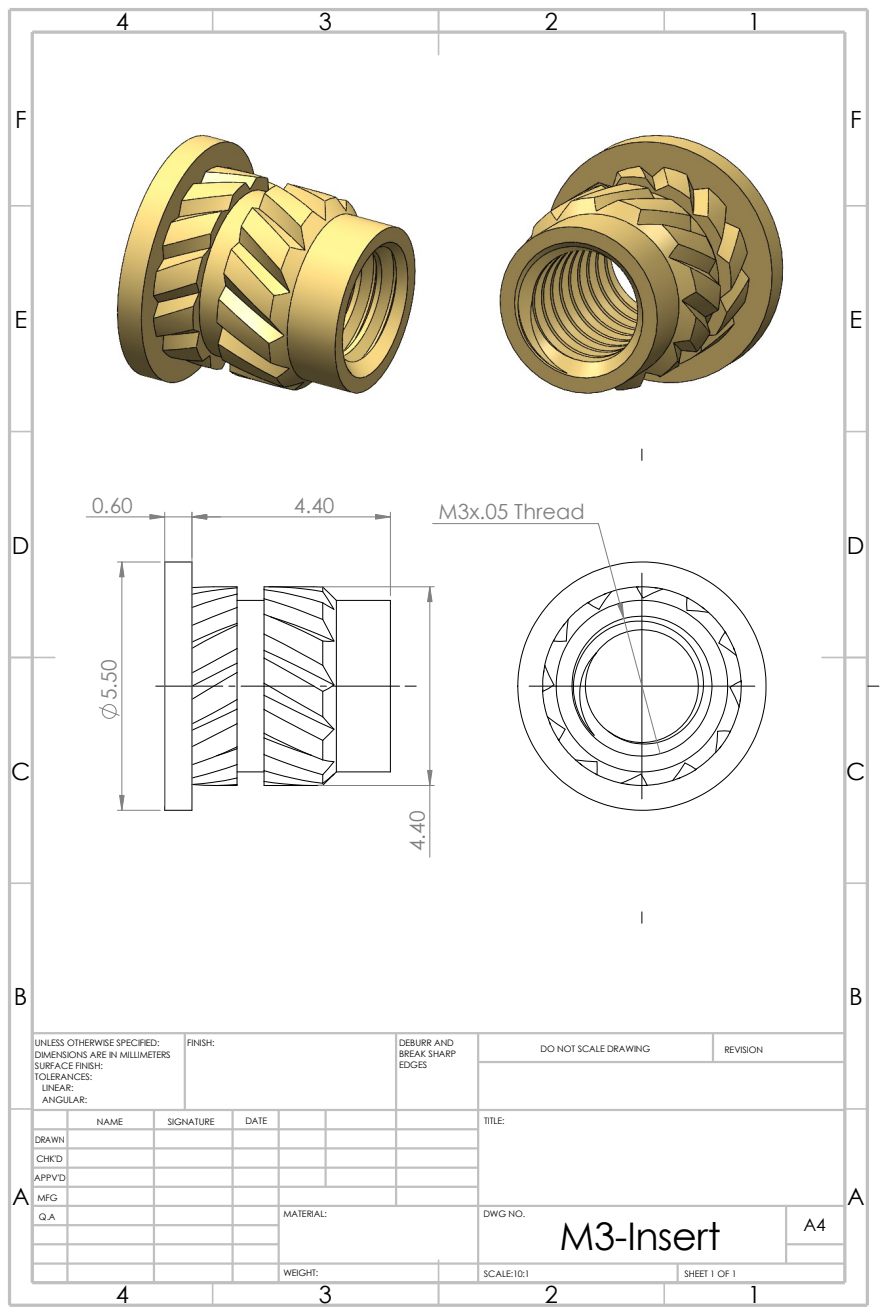
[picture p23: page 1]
SHEET 1 OF 1; WEIGHT:; SCALE:10:1; DWG NO.; DO NOT SCALE DRAWING; REVISION; MFG; FINISH:; EDGES; MATERIAL:; DEBURR AND BREAK SHARP; M3-Insert ⁵.50; 4.40 M3x.05 Thread

UNLESS OTHERWISE SPECIFIED:
DIMENSIONS ARE IN MILLIMETERS
SURFACE FINISH:
TOLERANCES:
LINEAR:
ANGULAR:

NAME | SIGNATURE | DATE | TITLE:

DRAWN
CHK'D
APPV'D

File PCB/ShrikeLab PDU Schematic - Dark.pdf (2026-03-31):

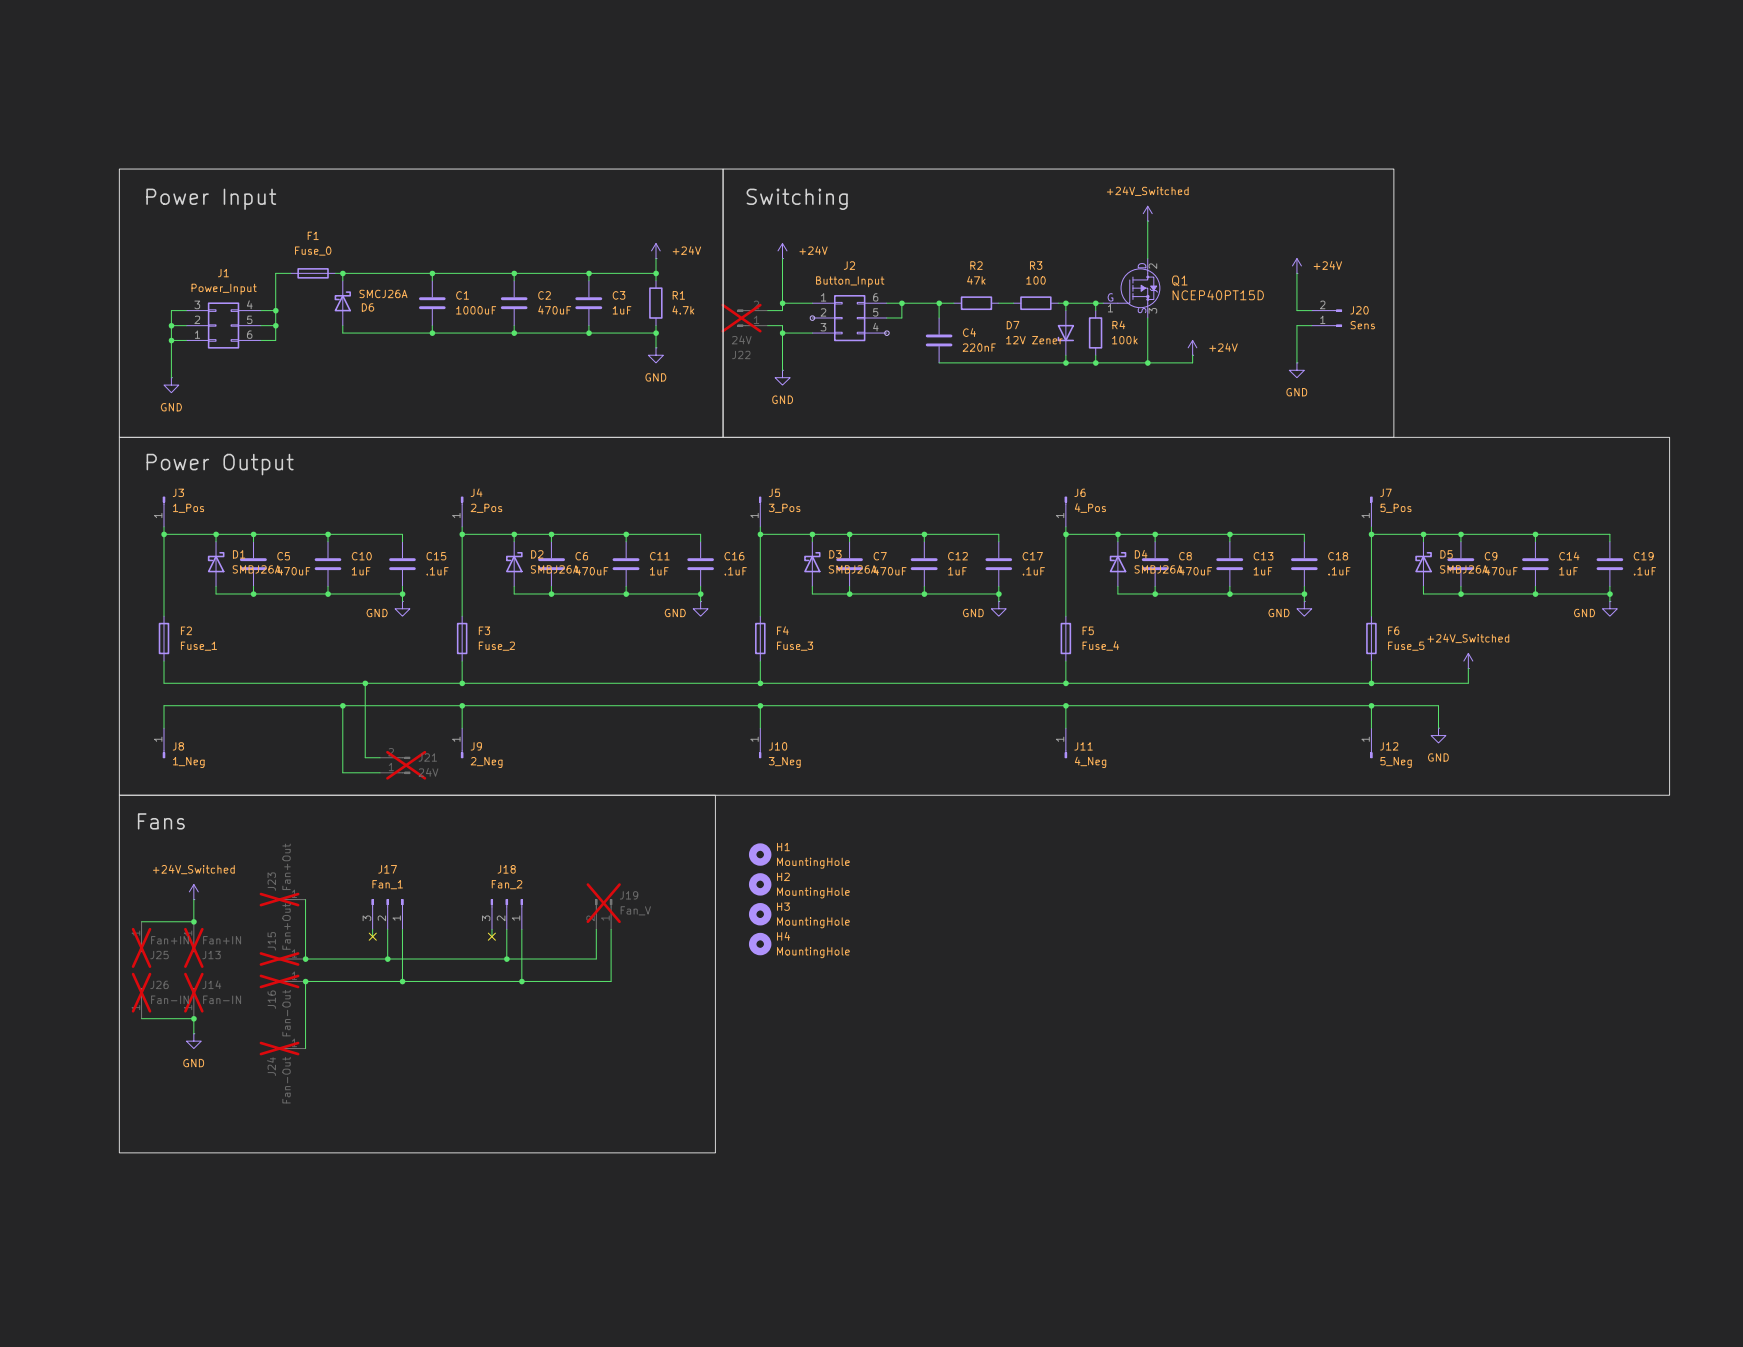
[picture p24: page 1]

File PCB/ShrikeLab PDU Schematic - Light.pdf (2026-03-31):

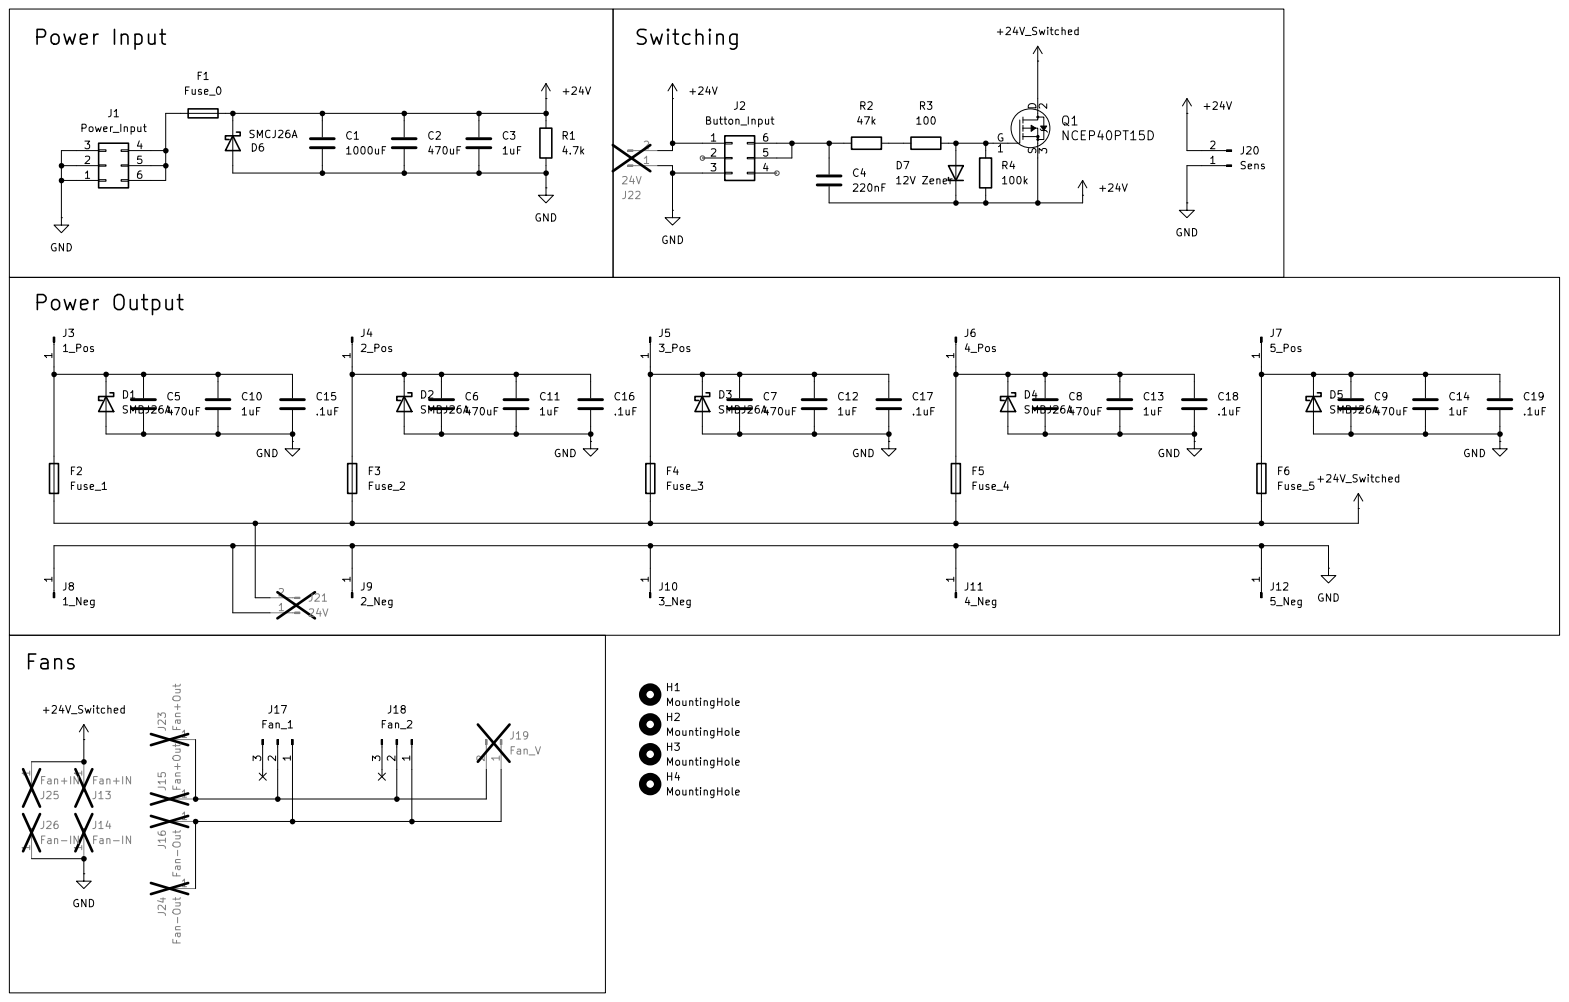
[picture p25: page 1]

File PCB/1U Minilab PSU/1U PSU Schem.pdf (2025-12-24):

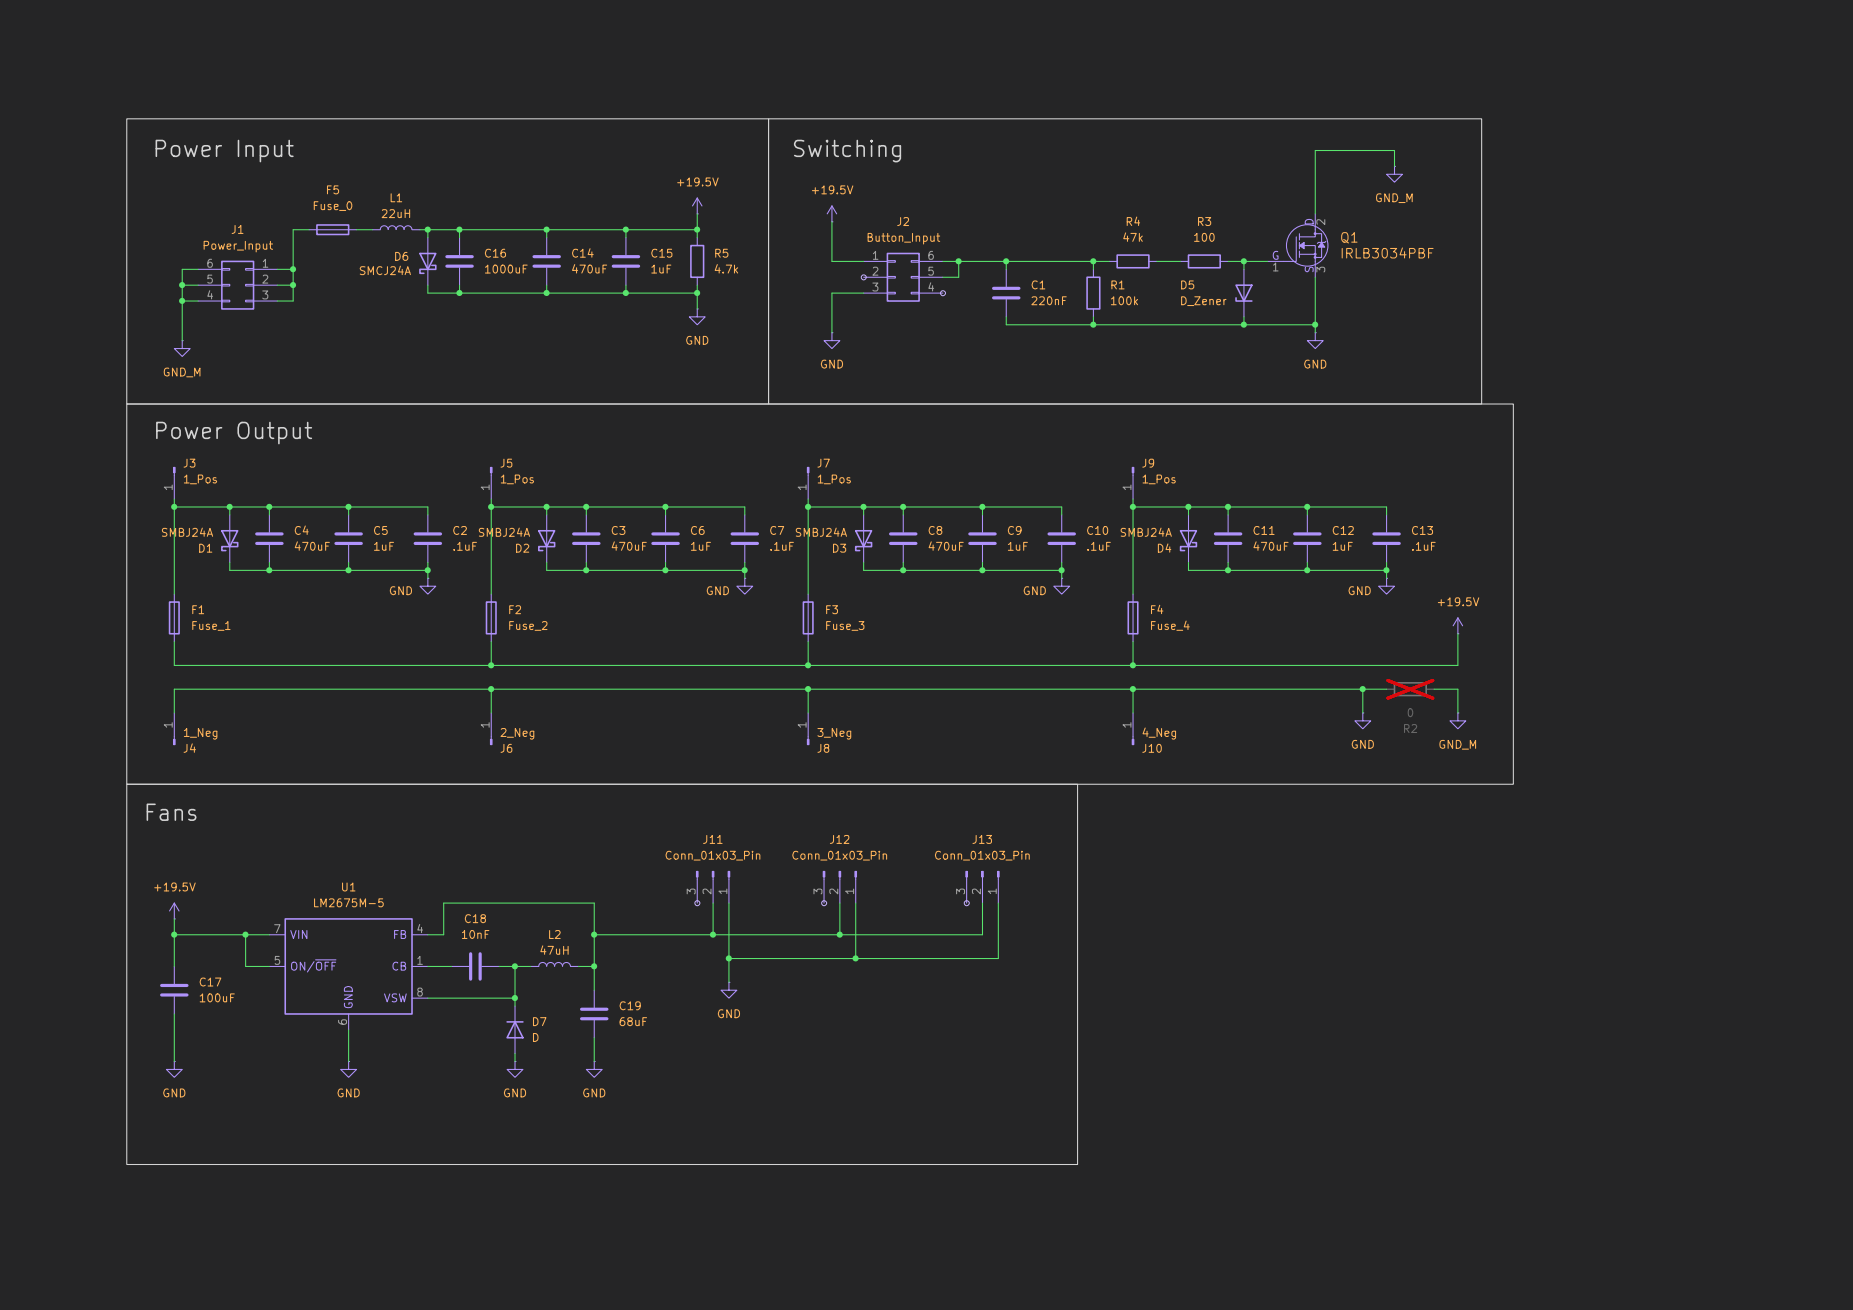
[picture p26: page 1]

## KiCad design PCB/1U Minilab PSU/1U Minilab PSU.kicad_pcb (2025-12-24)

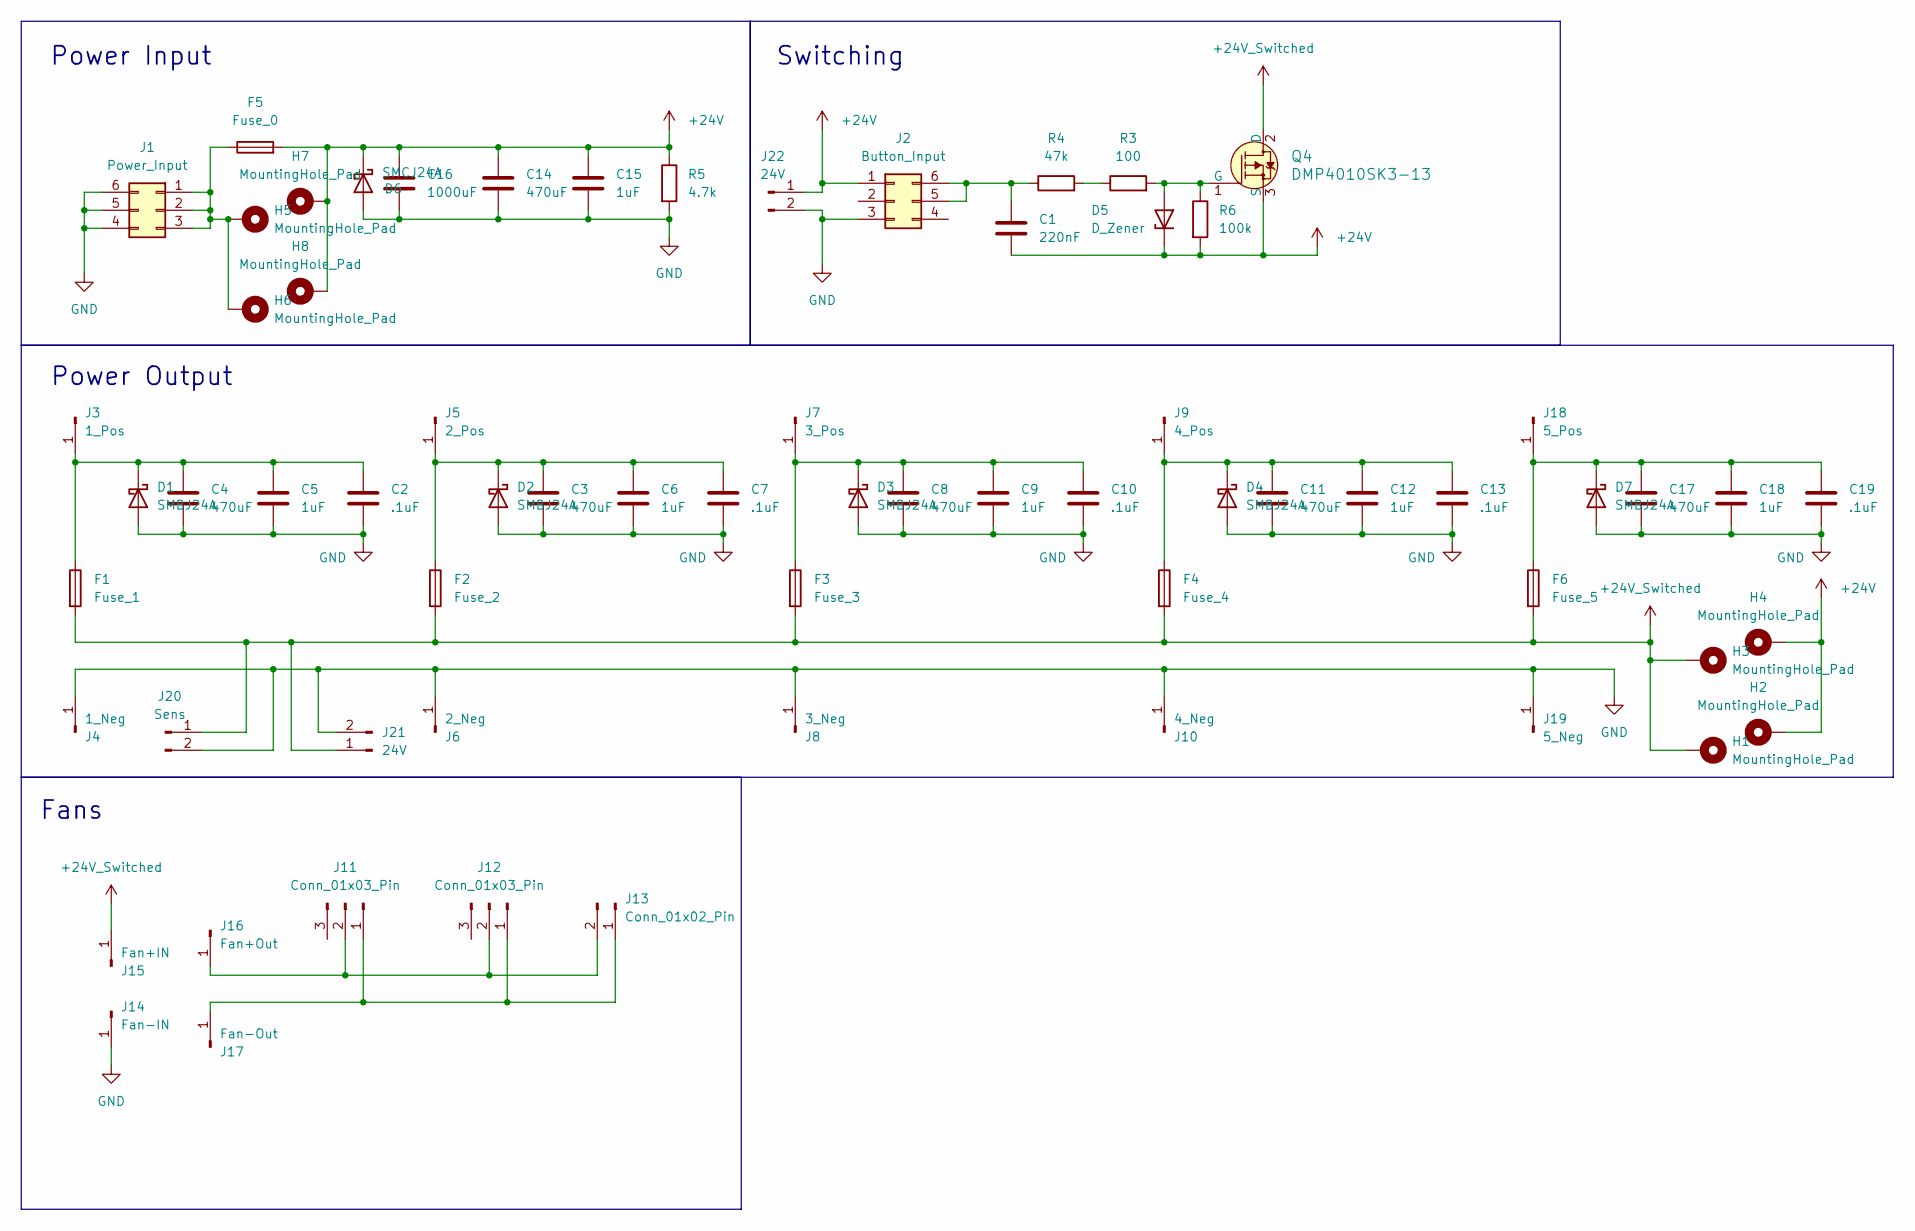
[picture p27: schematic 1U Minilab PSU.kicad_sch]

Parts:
C1: 220nF; C_0603_1608Metric_Pad1.08x0.95mm_HandSolder
C2, C7, C10, C13, C19: .1uF; C_0603_1608Metric_Pad1.08x0.95mm_HandSolder
C3, C4, C8, C11, C14, C17: 470uF; CP_Radial_D10.0mm_P5.00mm
C5, C6, C9, C12, C15, C18: 1uF; C_1206_3216Metric_Pad1.33x1.80mm_HandSolder
C16: 1000uF; CP_Radial_D10.0mm_P5.00mm
D1, D2, D3, D4, D7: SMBJ24A; D_SMB
D5: D_Zener; D_SOD-123
D6: SMCJ24A; D_SMB-SMC_Universal_Handsoldering
F1: Fuse_1; Fuse_1206_3216Metric_Pad1.42x1.75mm_HandSolder
F2: Fuse_2; Fuse_1206_3216Metric_Pad1.42x1.75mm_HandSolder
F3: Fuse_3; Fuse_1206_3216Metric_Pad1.42x1.75mm_HandSolder
F4: Fuse_4; Fuse_1206_3216Metric_Pad1.42x1.75mm_HandSolder
F5: Fuse_0; Fuse_1206_3216Metric_Pad1.42x1.75mm_HandSolder
F6: Fuse_5; Fuse_1206_3216Metric_Pad1.42x1.75mm_HandSolder
H1, H2, H3, H4, H5, H6, H7, H8: MountingHole_Pad; MountingHole_2.2mm_M2_DIN965_Pad_TopBottom
J1: Power_Input; Molex_Micro-Fit_3.0_43045-0600_2x03_P3.00mm_Horizontal
J2: Button_Input; Molex_Micro-Fit_3.0_43045-0600_2x03_P3.00mm_Horizontal
J3: 1_Pos; PinHeader_1x01_P2.54mm_Vertical
J4: 1_Neg; PinHeader_1x01_P2.54mm_Vertical
J5: 2_Pos; PinHeader_1x01_P2.54mm_Vertical
J6: 2_Neg; PinHeader_1x01_P2.54mm_Vertical
J7: 3_Pos; PinHeader_1x01_P2.54mm_Vertical
J8: 3_Neg; PinHeader_1x01_P2.54mm_Vertical
J9: 4_Pos; PinHeader_1x01_P2.54mm_Vertical
J10: 4_Neg; PinHeader_1x01_P2.54mm_Vertical
J11, J12: Conn_01x03_Pin; PinHeader_1x03_P2.54mm_Vertical
J13: Conn_01x02_Pin; PinHeader_1x02_P2.54mm_Vertical
J14: Fan-IN; PinHeader_1x01_P2.54mm_Vertical
J15: Fan+IN; PinHeader_1x01_P2.54mm_Vertical
J16: Fan+Out; PinHeader_1x01_P2.54mm_Vertical
J17: Fan-Out; PinHeader_1x01_P2.54mm_Vertical
J18: 5_Pos; PinHeader_1x01_P2.54mm_Vertical
J19: 5_Neg; PinHeader_1x01_P2.54mm_Vertical
J20: Sens; PinHeader_1x02_P2.54mm_Vertical
J21, J22: 24V; PinHeader_1x02_P2.54mm_Vertical
Q4: DMP4010SK3-13; TO-252-3_TabPin2; MPN IRF9540NPBF; Digi-Key_PN IRF9540NPBF-ND
R3: 100; R_0603_1608Metric
R4: 47k; R_0603_1608Metric
R5: 4.7k; R_1206_3216Metric
R6: 100k; R_0603_1608Metric

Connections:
+24V: C1.2, C14.1, C15.1, C16.1, D5.1 (K), D6.1 (K), F5.2, H2.1, H4.1, H7.1, H8.1, J2.1, J22.1, Q4.3 (S), R5.1, R6.2
+24V_Switched: F1.2, F2.2, F3.2, F4.2, F6.2, H1.1, H3.1, J15.1, J20.1, J21.1, Q4.2 (D)
GND: C2.2, C3.2, C4.2, C5.2, C6.2, C7.2, C8.2, C9.2, C10.2, C11.2, C12.2, C13.2, C14.2, C15.2, C16.2, C17.2, C18.2, C19.2, D1.2 (A), D2.2 (A), D3.2 (A), D4.2 (A), D6.2 (A), D7.2 (A), J1.4, J1.5, J1.6, J2.3, J4.1, J6.1, J8.1, J10.1, J14.1, J19.1, J20.2, J21.2, J22.2, R5.2
unnamed: C2.1, C4.1, C5.1, D1.1 (K), F1.1, J3.1
unnamed: C3.1, C6.1, C7.1, D2.1 (K), F2.1, J5.1
unnamed: C8.1, C9.1, C10.1, D3.1 (K), F3.1, J7.1
unnamed: C11.1, C12.1, C13.1, D4.1 (K), F4.1, J9.1
unnamed: D5.2 (A), Q4.1 (G), R3.2, R6.1
unnamed: C17.1, C18.1, C19.1, D7.1 (K), F6.1, J18.1
unnamed: F5.1, H5.1, H6.1, J1.1, J1.2, J1.3
unnamed: C1.1, J2.5, J2.6, R4.1
unnamed: J11.1, J12.1, J13.1, J17.1
unnamed: J11.2, J12.2, J13.2, J16.1
unnamed: R3.1, R4.2

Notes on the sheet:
Fans
Power Output
Power Input
Switching

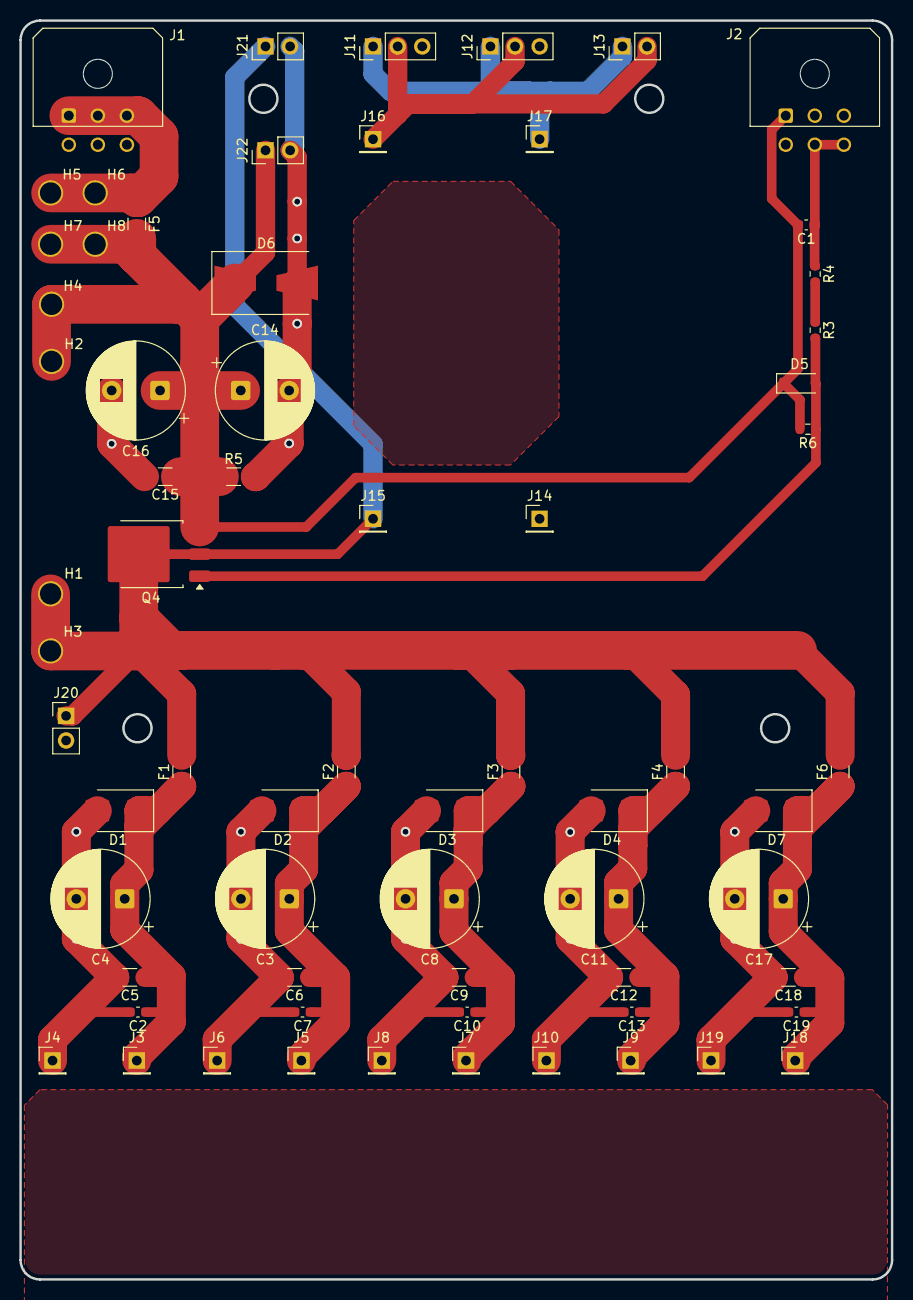
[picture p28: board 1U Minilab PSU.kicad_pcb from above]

Board: 2 copper layers, 90.0 x 130.0 mm, 67 parts (0 on the bottom side), 14 nets.

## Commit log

2025-12-24 Pushing KiCad files
    [1U Minilab PSU V2.csv, 1U Minilab PSU V2.kicad_pcb, 1U Minilab PSU V2.kicad_sch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]
2025-12-27 changing footprint of mosfet
    [1U Minilab PSU V2.csv, 1U Minilab PSU V2.kicad_pcb, 1U Minilab PSU V2.kicad_sch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]
2026-02-23 Working on README
    [19in_Dual-Front_1.stl, 19in_Dual-Front_2.stl, 19in_Dual-Rear_1.stl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]
2026-03-15 insert drawing
2026-03-26 Added schematics
2026-03-31 changes to PCB
    [19in_Single-Front_1.stl, 19in_Single-Front_2.3mf, 19in_Single-Front_2.stl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]
2026-03-31 updated pcb
2026-04-01 added blanks
    [10in_Mod-Back-BLANK.STEP, 10in_Single-Back-BLANK.STL, 10in_Uni-Tray-BLANK.stl.STEP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]
2026-04-04 JLC and PCBWay exports
    [HomeLab-PSU-V1_BOM.csv, HomeLab-PSU-V1_positions.csv, bom.csv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]
2026-04-05 Fixed 19in single rear and added blank STEP
    [19in_Single-Rear_2-BLANK.STEP, 19in_Single-Rear_2.stl]
2026-07-25 Updated SBS divider and lid
    [19in_Dual_SBS-Divider.STL, 19in_Dual_SBS-Lid.stp]
2026-10-14 Added imperial CAD files for 10in single
